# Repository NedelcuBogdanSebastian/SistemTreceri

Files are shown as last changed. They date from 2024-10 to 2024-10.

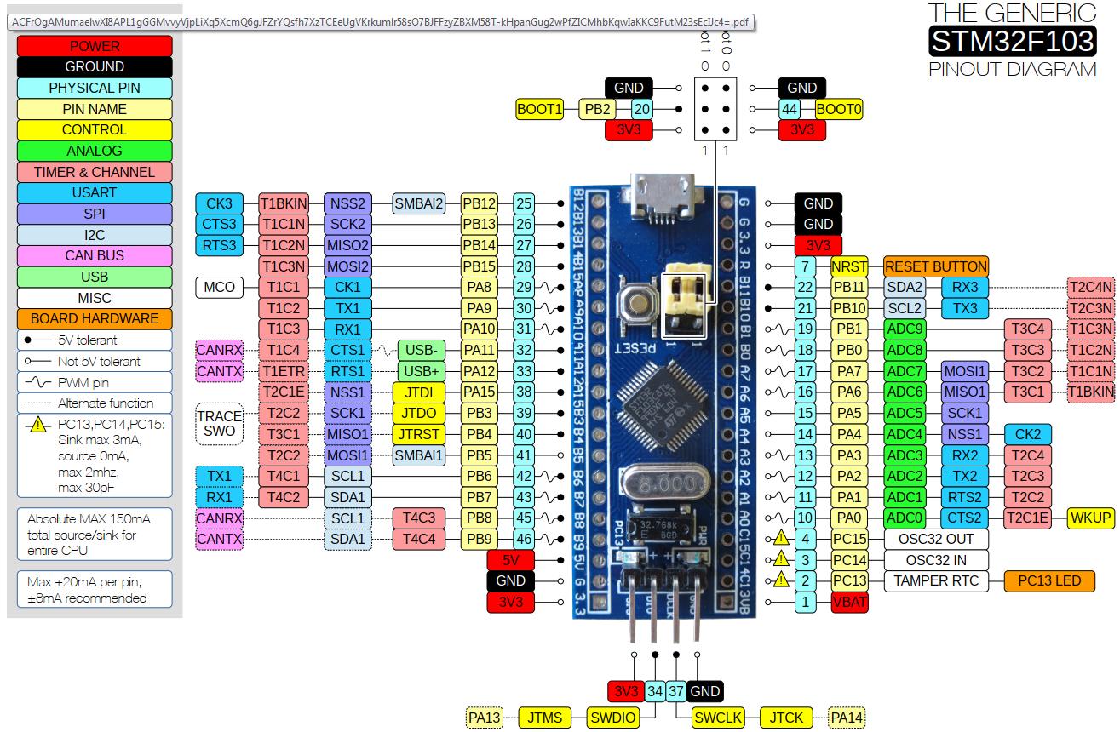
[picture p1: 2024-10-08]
Circuits/ZIntermediar2023/BLUEPILL-PINOUT.PNG

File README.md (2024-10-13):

display
# Copyright Notice
### Licence
Copyright (C) 2024 Nedelcu Bogdan Sebastian  
This code is free software: you can redistribute it and/or modify it under the following conditions:  
1. The use, distribution, and modification of this file are permitted for any purpose,  
   provided that the following conditions are met:  
2. Any redistribution or modification of this file must retain the original copyright notice,  
   this list of conditions, and the following attribution:  
      **"Original work by Nedelcu Bogdan Sebastian."**   
3. The original author provides no warranty regarding the functionality or fitness of this software  
   for any particular purpose. Use it at your own risk.  
By using this software, you agree to retain the name of the original author in any derivative works or distributions.  
This code is provided as-is, without any express or implied warranties.

# treceri
This is the main project used to acquire leakage currents signals, 
and compute **RMS voltage** and **phase** for each of the six channels.

The acquisition is starting after a **zero-cross detection**, and the length
of data is **2048 samples**.

The limits of the signals are between **2.678 mA** and **100 mA**.

More explanations of the algorithms are in the **main.c** file.

*(Note: The code runs on BluePill (STM32F103CBT6) and the IDE is the CooCox 1.7.8.
        The compiler used is the  gcc-arm-none-eabi-10.3-2021.10-win32.exe.
        Use external 23K256 SRAM memory to store all 6 signals at once!)*

# TestFFTPhaseComputation
This project also runs on the **STM32F103CBT6**.

Here we generate sine waves with phases from 0 to 359 degrees, and add noise to 
each signal and compute the phase angle from FFT.

The BluePill will show on the PC side as a **USB SERIAL** device, and we use this method
to print all values over **SERIAL**, the initial **signal phase** and the **computed phase** 
to further analyze them with Python if needed.

**Termite serial** can be used to receive data.

*(Note: The values are scaled by a factor of 10000 !)*

# treceriTestPhaseComputing

This project is made in **Visual Studio Code**. The compiler used is **tdm64-gcc-10.3.0-2**.

In this example we have the following:

    - we generate signals from 0 degrees to 359 degrees,
      of specific phase and noise, and write the values to files named `sine_wave_x.x.txt`,
      with 1.0 degree step
      
    - we generate the Flattop window and write coeffs to a file `flattop_window.txt`
    
    - we apply the window to the signal real side
    
    - we compute FFT
    
    - we compute the phase from bin 9 which is the nearest frequency from 50 Hz (51.4984130859375 Hz)

    - print computed data and repeat until the phase is >= 360.0 degrees
    
We also have some **Python** scripts we can use to see the signals from the files:

    - the `animate_plot_files.py` loads text files, one after another, 
      and plot the signal and the FFT
      
    - the `plot_sine_wave.py` plot only one file
    
    - the `gen_sig_hanning.py` generate a signal and apply hanning window. 
      Also compute phase.

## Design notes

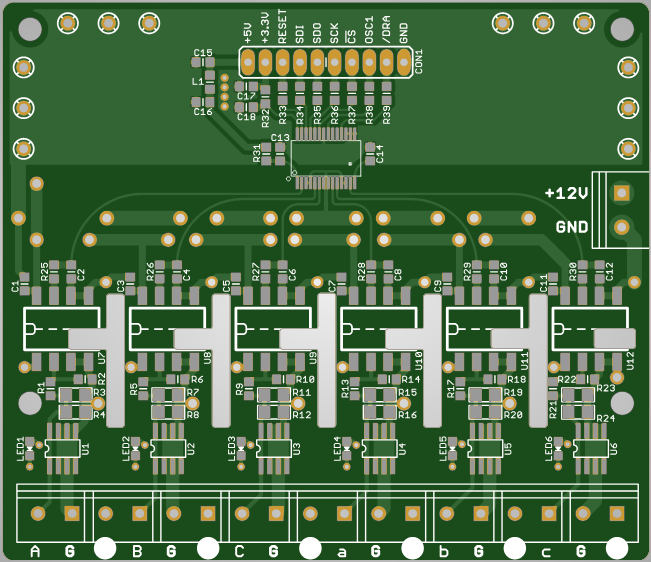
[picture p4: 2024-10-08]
Circuits/Zaq_ISO/Top.png

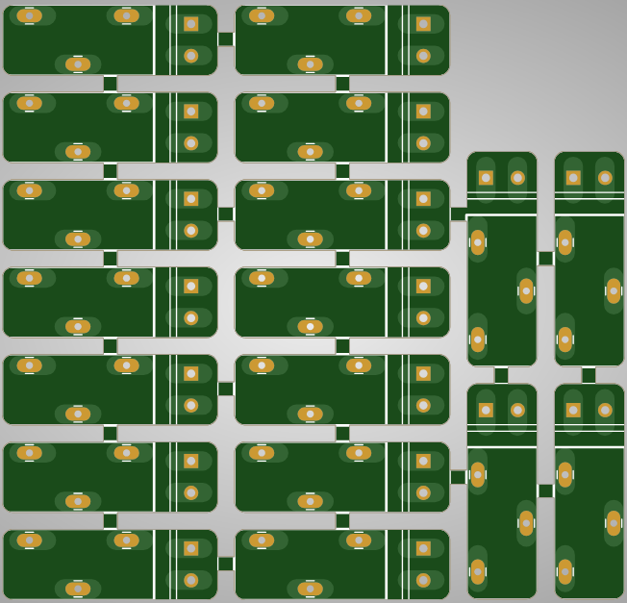
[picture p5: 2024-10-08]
Circuits/CT_Adapter/Top.png

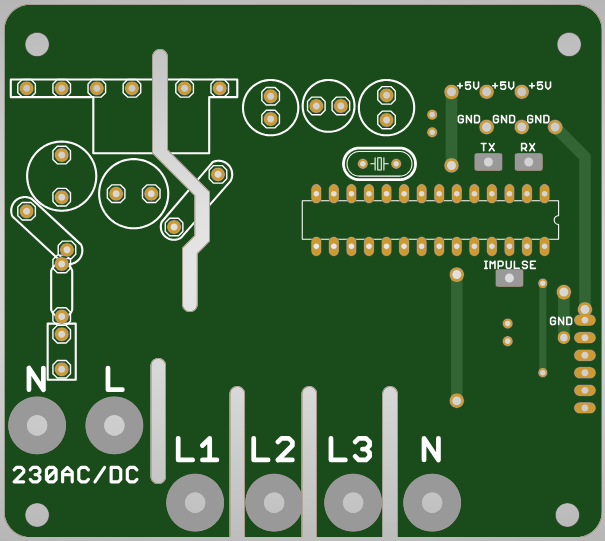
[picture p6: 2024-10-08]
Circuits/ZEROCROSS_ATmega328/Top.png

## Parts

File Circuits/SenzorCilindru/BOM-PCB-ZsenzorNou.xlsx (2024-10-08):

COMPONENTE
1x FAIR-RITE - 2944666661 - FERRITE CORE, CYLINDRICAL, 470 OHM
2x EPCOS - B88069X1380S102 - GAS DISCHARGE TUBE, 90V
4x SR PASSIVES MPEM-470NR15/250, CAPACITORS

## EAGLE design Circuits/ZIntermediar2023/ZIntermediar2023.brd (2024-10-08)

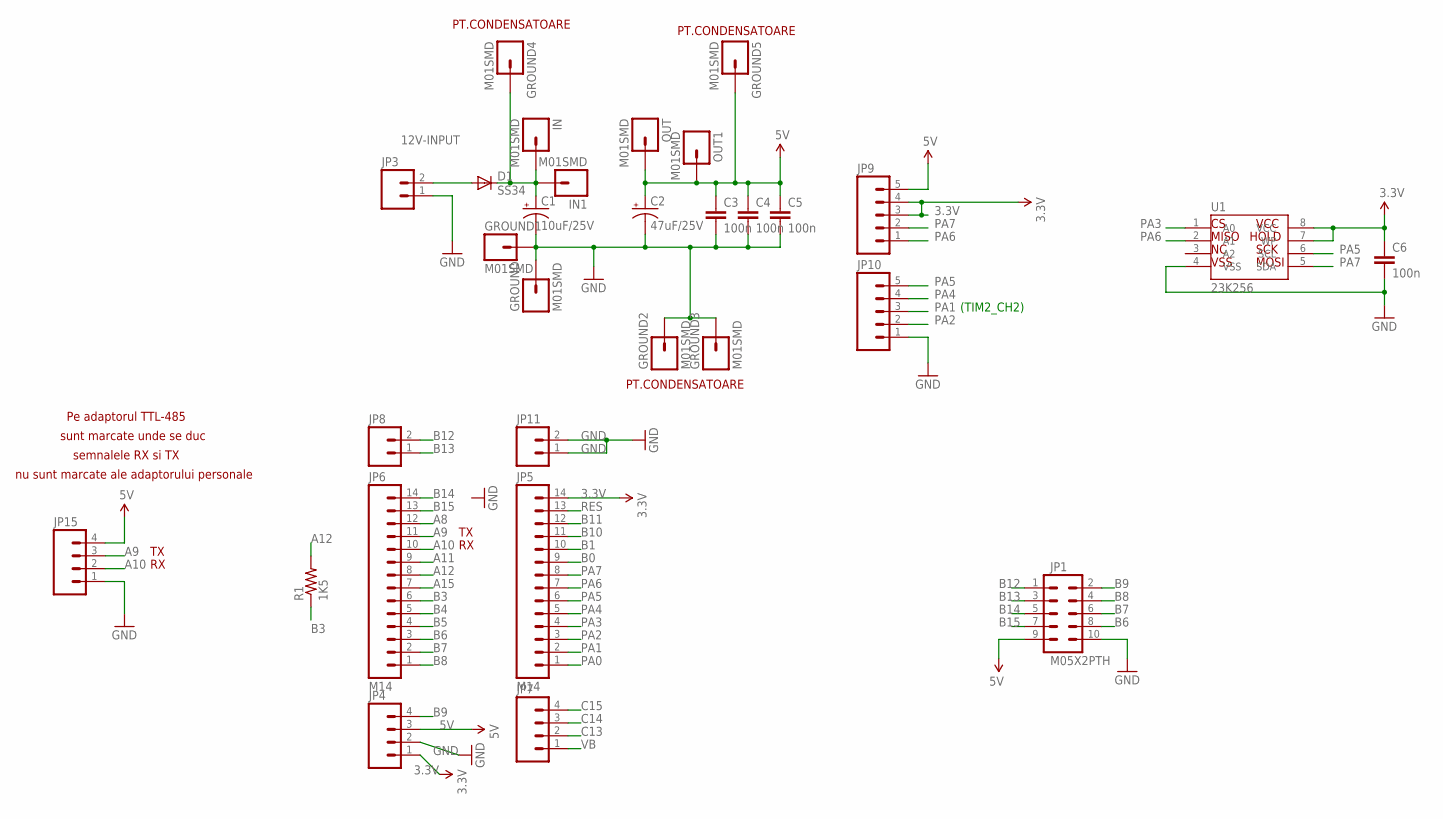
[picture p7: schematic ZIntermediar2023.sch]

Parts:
C1: 10uF/25V; PANASONIC_E
C2: 47uF/25V; PANASONIC_E
C3, C4, C5, C6: 100n; 1206
D1: SS34; SMC
GROUND, GROUND1, GROUND2, GROUND3, GROUND4, GROUND5: M01SMD; LUXEON-PAD
IN, IN1: M01SMD; LUXEON-PAD
JP1: M05X2PTH; AVR_ICSP
JP3: M025MM; SCREWTERMINAL-5MM-2
JP4, JP7: M04PTH; 1X04
JP5, JP6: M14; 1X14
JP8, JP11: M02PTH; 1X02
JP9, JP10: M05PTH_LONGPADS; 1X05_LONGPADS
JP15: M04LONGPADS; 1X04_LONGPADS
OUT, OUT1: M01SMD; LUXEON-PAD
R1: 1K5; 1206
U1: 23K256; SO08

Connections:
3.3V: C6.1, JP4.1, JP5.14, JP9.3, JP9.4, U1.7 (WP), U1.8 (VCC)
5V: C2.+, C3.1, C4.1, C5.1, GROUND5.P$1, JP1.9, JP4.3, JP9.5, JP15.4, OUT.P$1, OUT1.P$1
12V-INPUT: C1.+, D1.C, GROUND4.P$1, IN.P$1, IN1.P$1
A8: JP6.12
A9: JP6.11, JP15.3
A10: JP6.10, JP15.2
A11: JP6.9
A12: JP6.8, R1.2
A15: JP6.7
B0: JP5.9
B1: JP5.10
B3: JP6.6, R1.1
B4: JP6.5
B5: JP6.4
B6: JP1.8, JP6.3
B7: JP1.6, JP6.2
B8: JP1.4, JP6.1
B9: JP1.2, JP4.4
B10: JP5.11
B11: JP5.12
B12: JP1.1, JP8.2
B13: JP1.3, JP8.1
B14: JP1.5, JP6.14
B15: JP1.7, JP6.13
C13: JP7.2
C14: JP7.3
C15: JP7.4
GND: C1.-, C2.-, C3.2, C4.2, C5.2, C6.2, GROUND.P$1, GROUND1.P$1, GROUND2.P$1, GROUND3.P$1, JP1.10, JP3.1, JP4.2, JP10.1, JP11.1, JP11.2, JP15.1, U1.4 (VSS)
unnamed: D1.A, JP3.2
PA0: JP5.1
PA1: JP5.2, JP10.3
PA2: JP5.3, JP10.2
PA3: JP5.4, U1.1 (A0)
PA4: JP5.5, JP10.4
PA5: JP5.6, JP10.5, U1.6 (SCL)
PA6: JP5.7, JP9.1, U1.2 (A1)
PA7: JP5.8, JP9.2, U1.5 (SDA)
RES: JP5.13
VB: JP7.1

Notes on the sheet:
(TIM2_CH2)
MISO
VSS
VCC
HOLD
SCK
MOSI
PT.CONDENSATOARE
Pe adaptorul TTL-485
sunt marcate unde se duc
semnalele RX si TX
nu sunt marcate ale adaptorului personale

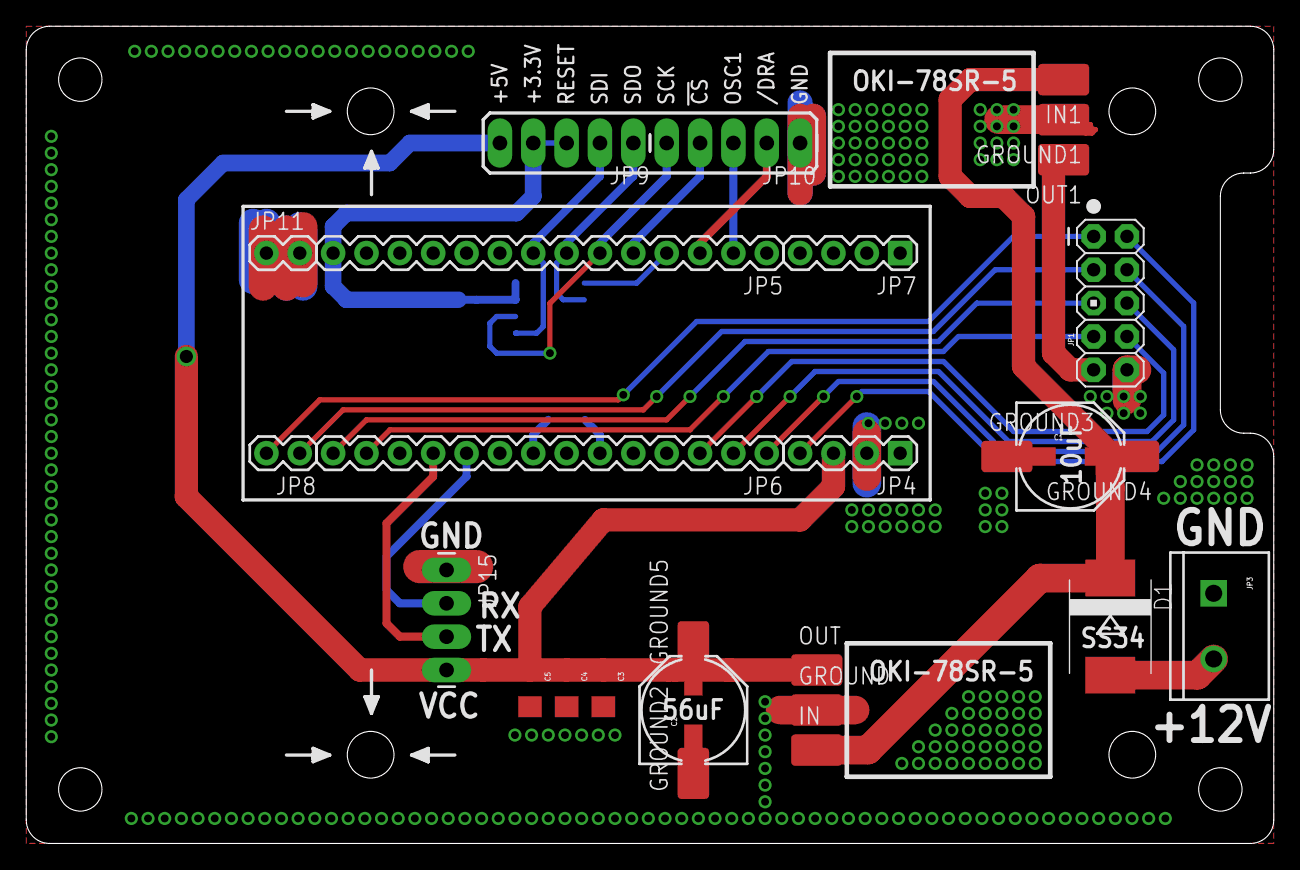
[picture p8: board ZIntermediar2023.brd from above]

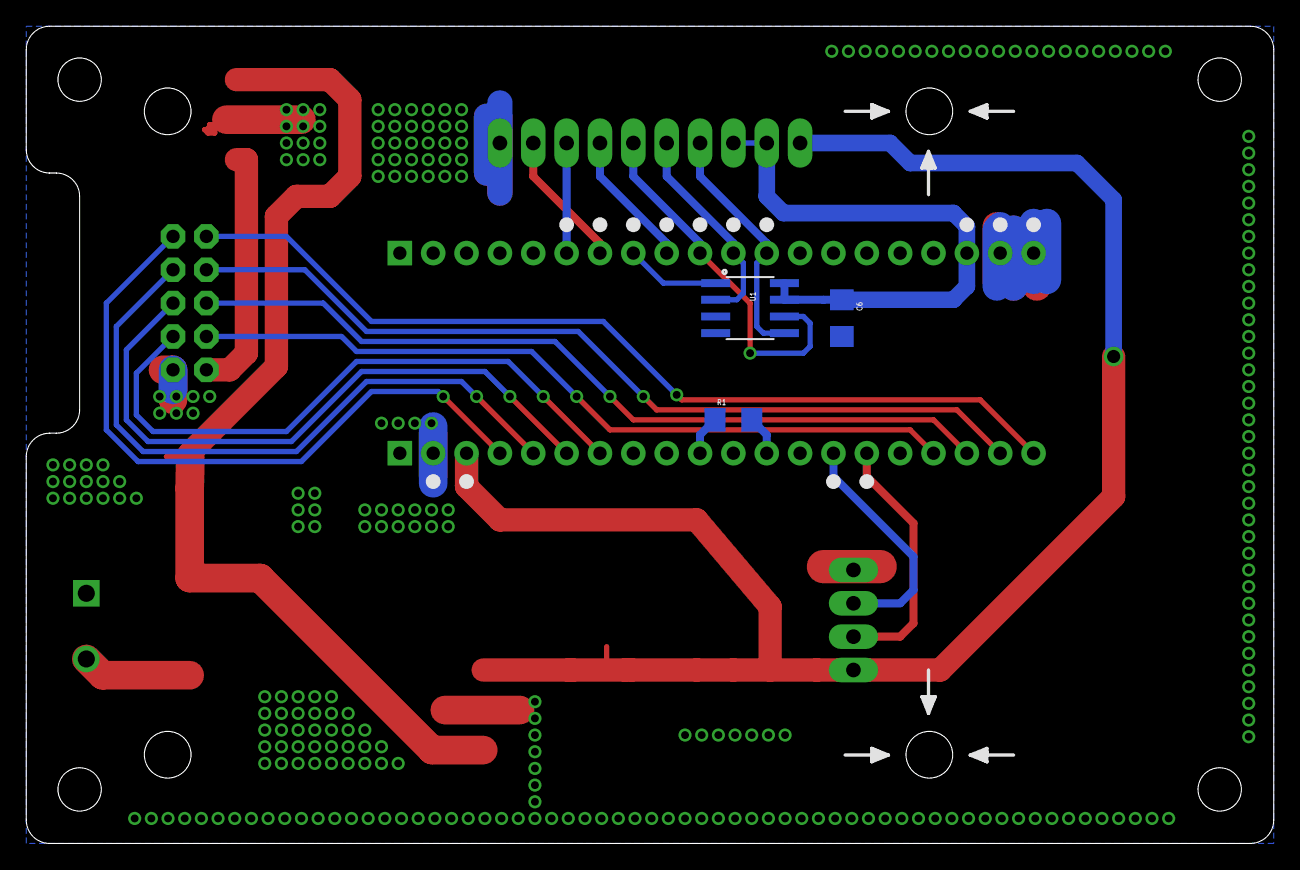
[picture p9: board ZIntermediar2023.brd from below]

Board: 2 copper layers, 95.0 x 62.2 mm, 34 parts (3 on the bottom side), 24 nets.

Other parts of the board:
STANDOFF1, STANDOFF6, STANDOFF10, STANDOFF12: STAND-OFF

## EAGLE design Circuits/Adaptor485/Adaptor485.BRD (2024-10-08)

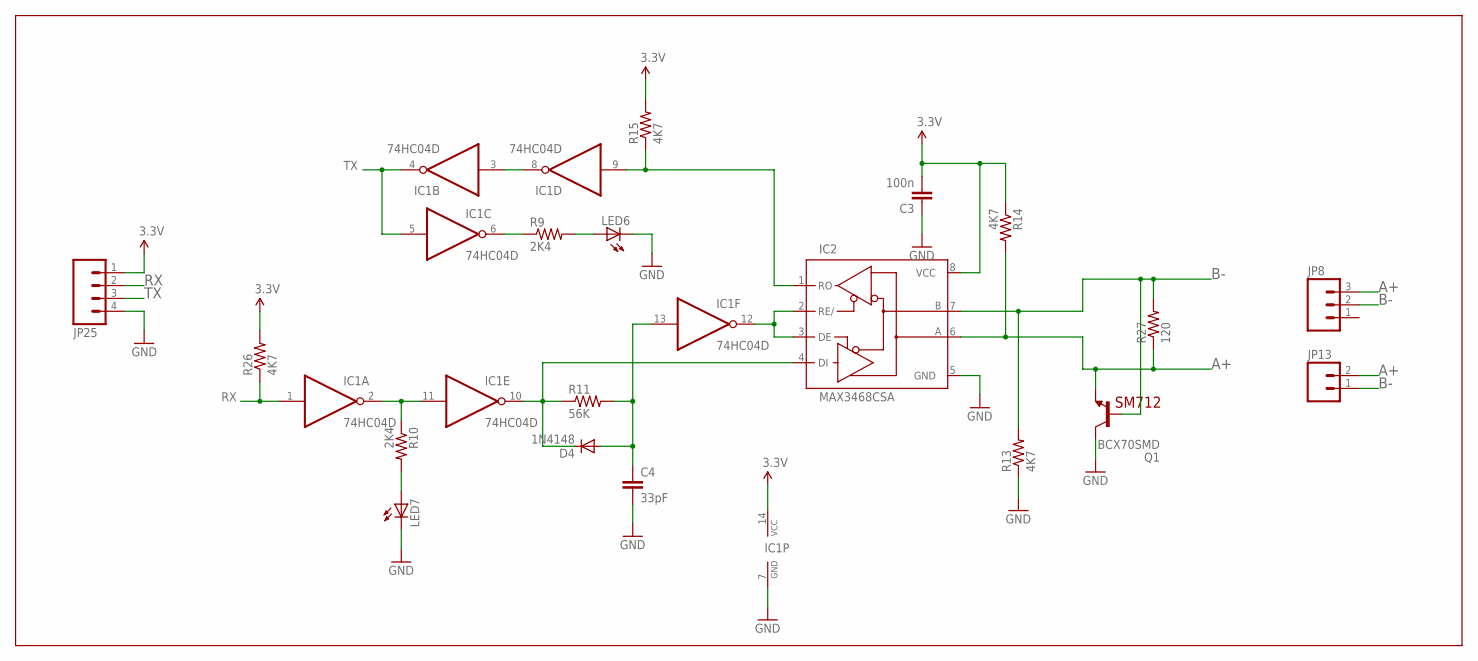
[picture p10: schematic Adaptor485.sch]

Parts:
C3: 100n; 0805
C4: 33pF; 0805
D4: 1N4148; MINIMELF
IC1: 74HC04D; SO14
IC2: MAX3468CSA; SO08
JP8: M03-SCREW-5MM; SCREWTERMINAL-5MM-3
JP13: M025MM; SCREWTERMINAL-5MM-2
JP25: M04PTH; 1X04
LED6, LED7: LEDCHIP-LED0805; CHIP-LED0805
Q1: BCX70SMD; SOT23
R9, R10: 2K4; 0805
R11: 56K; 0805
R13, R14, R15, R26: 4K7; 0805
R27: 120; 0805

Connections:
3.3V: C3.2, IC1.14 (VCC), IC2.8 (VCC), JP25.1, R14.1, R15.2, R26.2
A+: IC2.6 (A), JP8.3, JP13.2, Q1.2 (E), R14.2, R27.1
B-: IC2.7 (B), JP8.2, JP13.1, Q1.1 (B), R13.2, R27.2
GND: C3.1, C4.2, IC1.7 (GND), IC2.5 (GND), JP25.4, LED6.C, LED7.C, Q1.3 (C), R13.1
unnamed: LED7.A, R10.2
unnamed: LED6.A, R9.2
unnamed: IC1.2 (O), IC1.11 (I), R10.1
unnamed: IC1.9 (I), IC2.1 (RO), R15.1
unnamed: IC1.3 (I), IC1.8 (O)
unnamed: C4.1, D4.A, IC1.13 (I), R11.2
unnamed: IC1.6 (O), R9.1
unnamed: D4.C, IC1.10 (O), IC2.4 (DI), R11.1
unnamed: IC1.12 (O), IC2.2 (RE/), IC2.3 (DE)
RX: IC1.1 (I), JP25.2, R26.1
TX: IC1.4 (O), IC1.5 (I), JP25.3

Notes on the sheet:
SM712

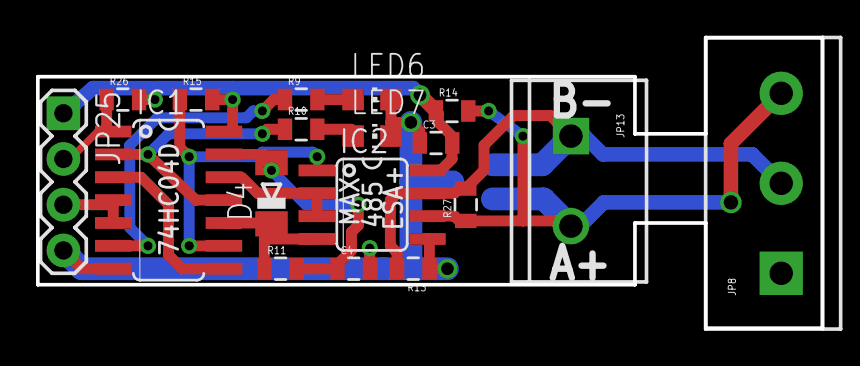
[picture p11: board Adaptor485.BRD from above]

Board: 2 copper layers, 43.6 x 16.1 mm, 19 parts (1 on the bottom side), 15 nets.

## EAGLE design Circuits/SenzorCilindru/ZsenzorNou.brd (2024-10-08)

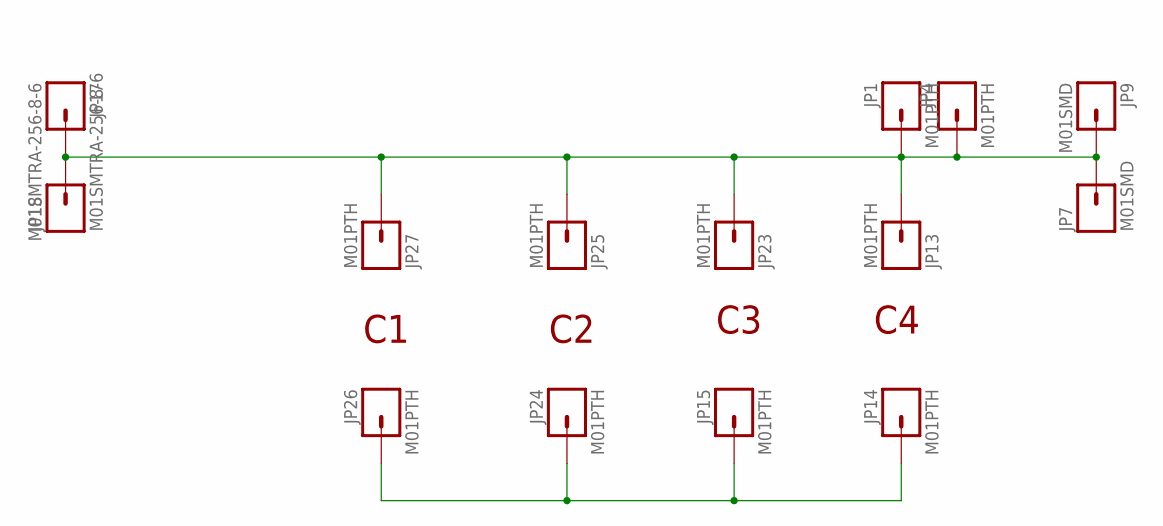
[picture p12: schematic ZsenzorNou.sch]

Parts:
JP1, JP4, JP13, JP14, JP15, JP23, JP24, JP25, JP26, JP27: M01PTH; 1X01
JP7, JP9: M01SMD; LUXEON-PAD
JP17, JP18: M01SMTRA-256-8-6; SMTRA-256-8-6

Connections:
GND: JP14.1, JP15.1, JP24.1, JP26.1
unnamed: JP1.1, JP4.1, JP7.P$1, JP9.P$1, JP13.1, JP17.P$1, JP18.P$1, JP23.1, JP25.1, JP27.1

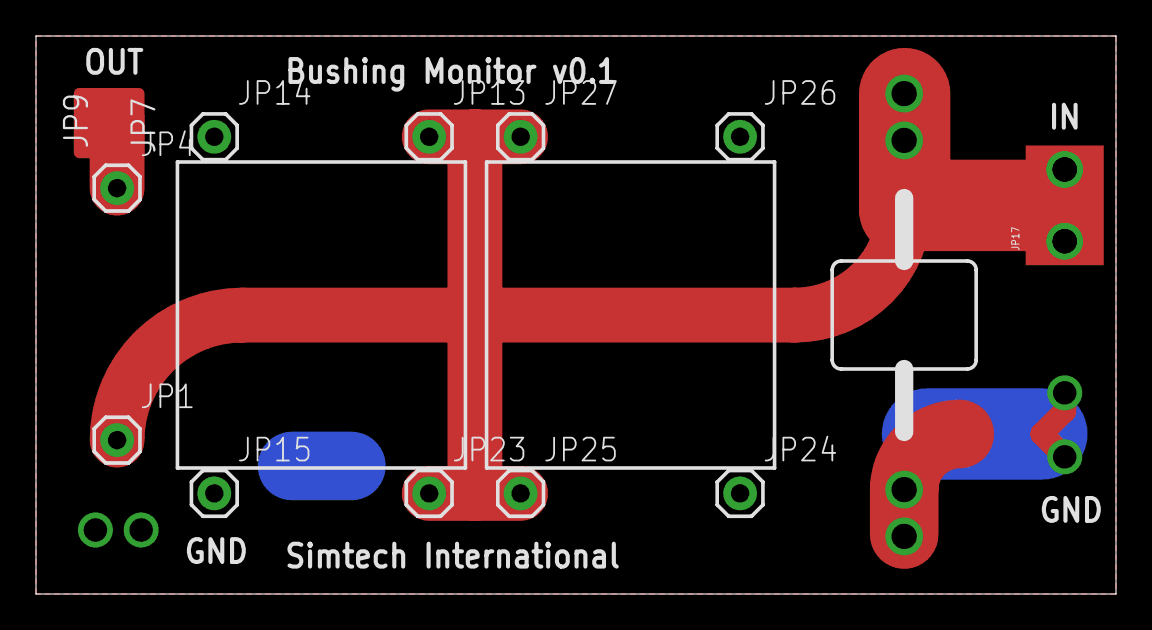
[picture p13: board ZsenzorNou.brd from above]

Board: 2 copper layers, 60.0 x 31.0 mm, 14 parts (1 on the bottom side), 2 nets.

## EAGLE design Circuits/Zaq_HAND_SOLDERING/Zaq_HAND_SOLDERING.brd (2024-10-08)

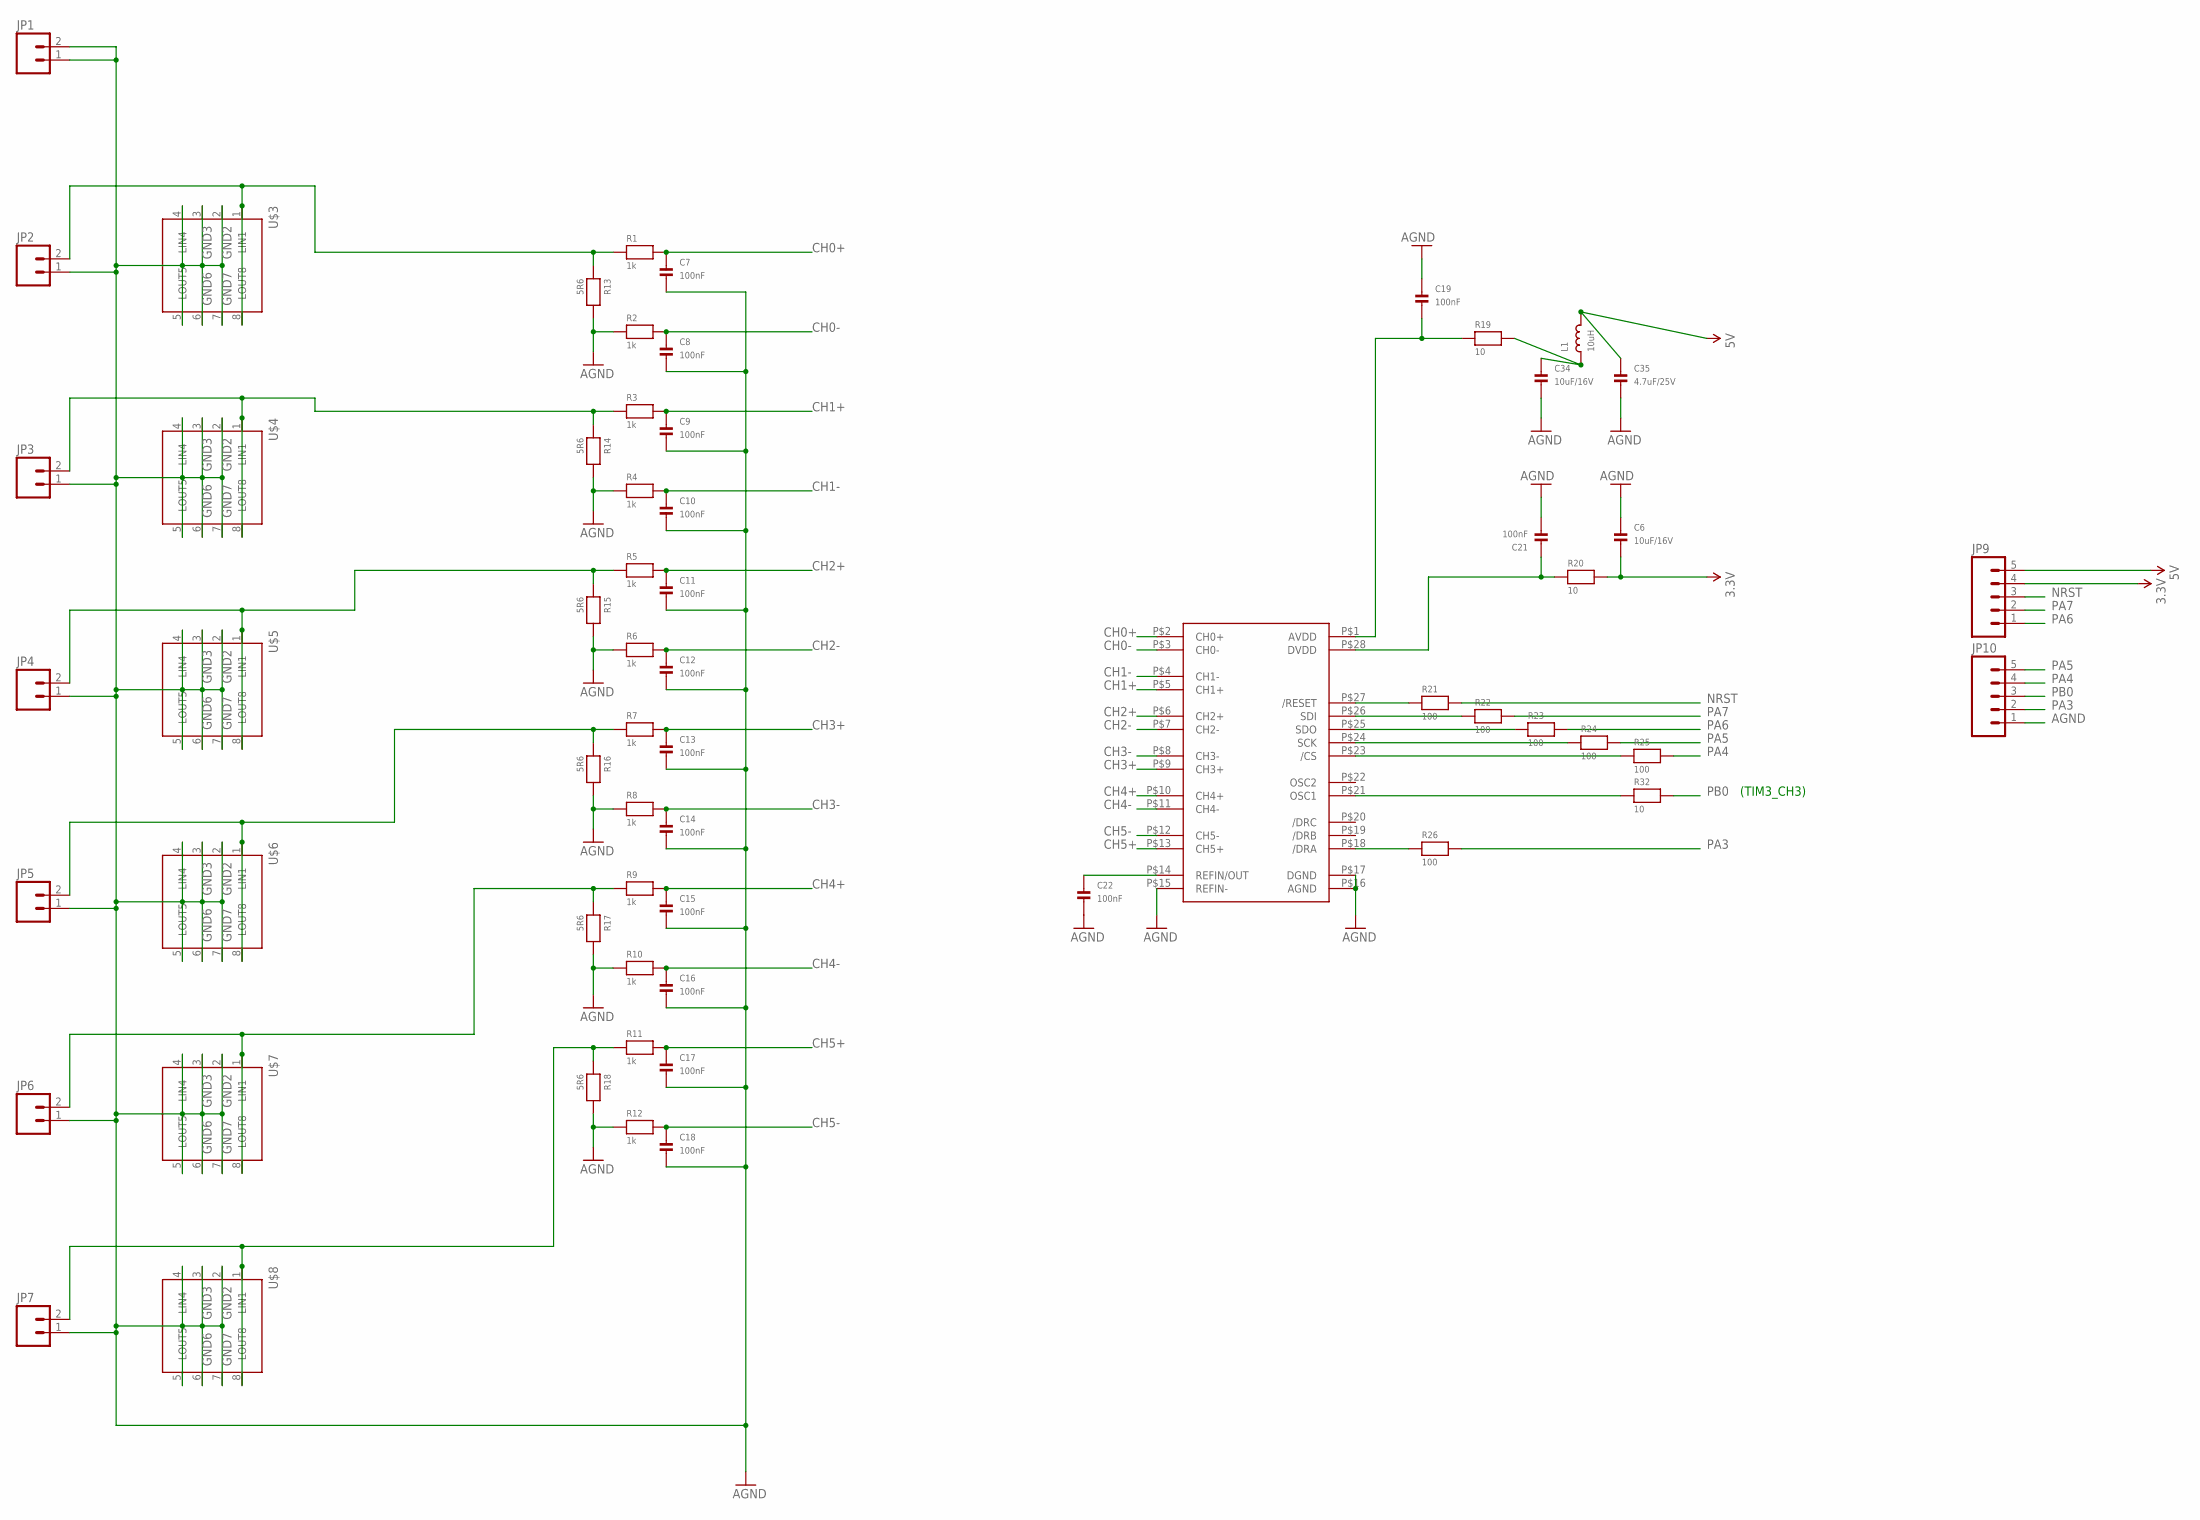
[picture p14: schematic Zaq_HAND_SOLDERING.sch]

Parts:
.: MCP3903; SSOP-28
C6, C34: 10uF/16V; _0805MP
C7, C8, C9, C10, C11, C12, C13, C14, C15, C16, C17, C18, C19, C21, C22: 100nF; _0805MP
C35: 4.7uF/25V; _0805MP
JP1, JP2, JP3, JP4, JP5, JP6, JP7: M025MM; SCREWTERMINAL-5MM-2
JP9, JP10: M05PTH_LONGPADS; 1X05_LONGPADS
L1: 10uH; _0805MP
R1, R2, R3, R4, R5, R6, R7, R8, R9, R10, R11, R12: 1k; _0805MP
R13, R14, R15, R16, R17, R18: 5R6; 1206
R19, R20, R32: 10; _0805MP
R21, R22, R23, R24, R25, R26: 100; _0805MP
U$3, U$4, U$5, U$6, U$7, U$8: LC03_3V3; SO8

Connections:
3.3V: C6.2, JP9.4, R20.2
5V: C35.1, JP9.5, L1.2
AGND: ..P$15 (REFIN-), ..P$16 (AGND), ..P$17 (DGND), C6.1, C7.2, C8.2, C9.2, C10.2, C11.2, C12.2, C13.2, C14.2, C15.2, C16.2, C17.2, C18.2, C19.1, C21.2, C22.2, C34.2, C35.2, JP1.1, JP1.2, JP2.1, JP3.1, JP4.1, JP5.1, JP6.1, JP7.1, JP10.1, R2.1, R4.1, R6.1, R8.1, R10.1, R12.1, R13.2, R14.2, R15.2, R16.2, R17.2, R18.2, U$3.2 (GND_2), U$3.3 (GND_3), U$3.4 (LIN4), U$3.5 (LOUT5), U$3.6 (GND_6), U$3.7 (GND_7), U$4.2 (GND_2), U$4.3 (GND_3), U$4.4 (LIN4), U$4.5 (LOUT5), U$4.6 (GND_6), U$4.7 (GND_7), U$5.2 (GND_2), U$5.3 (GND_3), U$5.4 (LIN4), U$5.5 (LOUT5), U$5.6 (GND_6), U$5.7 (GND_7), U$6.2 (GND_2), U$6.3 (GND_3), U$6.4 (LIN4), U$6.5 (LOUT5), U$6.6 (GND_6), U$6.7 (GND_7), U$7.2 (GND_2), U$7.3 (GND_3), U$7.4 (LIN4), U$7.5 (LOUT5), U$7.6 (GND_6), U$7.7 (GND_7), U$8.2 (GND_2), U$8.3 (GND_3), U$8.4 (LIN4), U$8.5 (LOUT5), U$8.6 (GND_6), U$8.7 (GND_7)
CH0+: ..P$2 (CH0+), C7.1, R1.2
CH0-: ..P$3 (CH0-), C8.1, R2.2
CH1+: ..P$5 (CH1+), C9.1, R3.2
CH1-: ..P$4 (CH1-), C10.1, R4.2
CH2+: ..P$6 (CH2+), C11.1, R5.2
CH2-: ..P$7 (CH2-), C12.1, R6.2
CH3+: ..P$9 (CH3+), C13.1, R7.2
CH3-: ..P$8 (CH3-), C14.1, R8.2
CH4+: ..P$10 (CH4+), C15.1, R9.2
CH4-: ..P$11 (CH4-), C16.1, R10.2
CH5+: ..P$13 (CH5+), C17.1, R11.2
CH5-: ..P$12 (CH5-), C18.1, R12.2
unnamed: ..P$21 (OSC1), R32.1
unnamed: ..P$1 (AVDD), C19.2, R19.1
unnamed: ..P$14 (REFIN/OUT), C22.1
unnamed: ..P$28 (DVDD), C21.1, R20.1
unnamed: ..P$27 (/RESET), R21.1
unnamed: ..P$26 (SDI), R22.1
unnamed: ..P$25 (SDO), R23.1
unnamed: ..P$24 (SCK), R24.1
unnamed: ..P$23 (/CS), R25.1
unnamed: ..P$18 (/DRA), R26.1
unnamed: C34.1, L1.1, R19.2
unnamed: JP7.2, R11.1, R18.1, U$8.1 (LIN1), U$8.8 (LOUT8)
unnamed: JP6.2, R9.1, R17.1, U$7.1 (LIN1), U$7.8 (LOUT8)
unnamed: JP5.2, R7.1, R16.1, U$6.1 (LIN1), U$6.8 (LOUT8)
unnamed: JP4.2, R5.1, R15.1, U$5.1 (LIN1), U$5.8 (LOUT8)
unnamed: JP3.2, R3.1, R14.1, U$4.1 (LIN1), U$4.8 (LOUT8)
unnamed: JP2.2, R1.1, R13.1, U$3.1 (LIN1), U$3.8 (LOUT8)
NRST: JP9.3, R21.2
PA3: JP10.2, R26.2
PA4: JP10.4, R25.2
PA5: JP10.5, R24.2
PA6: JP9.1, R23.2
PA7: JP9.2, R22.2
PB0: JP10.3, R32.2

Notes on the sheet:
(TIM3_CH3)

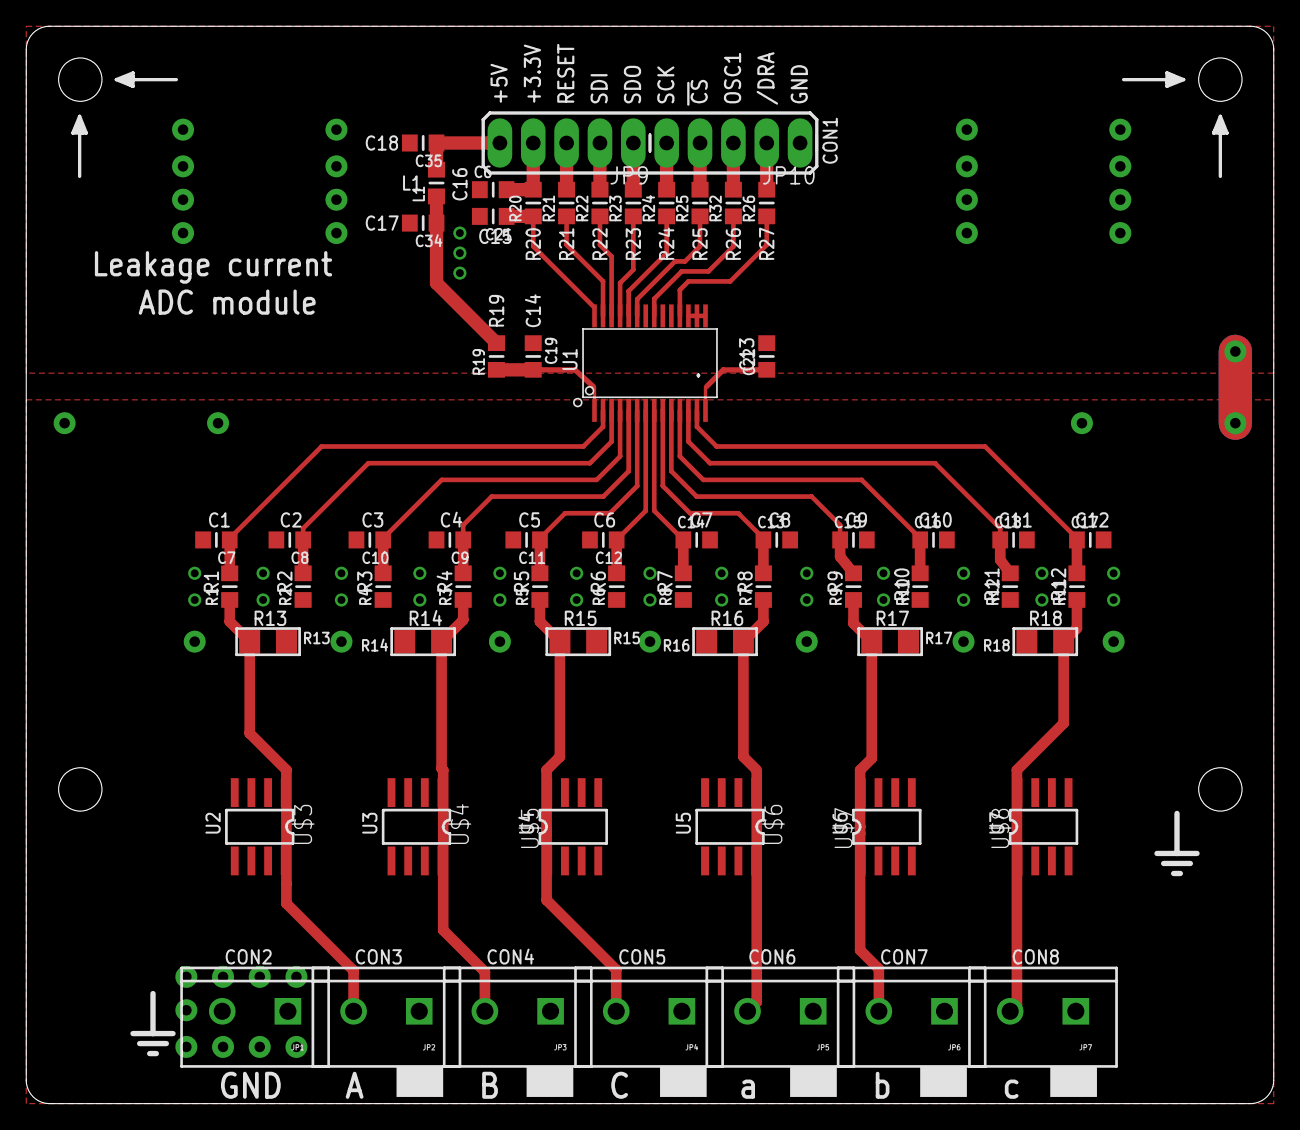
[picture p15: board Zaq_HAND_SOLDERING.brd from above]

Board: 2 copper layers, 95.0 x 82.0 mm, 66 parts (0 on the bottom side), 39 nets.

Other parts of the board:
STANDOFF1, STANDOFF6, STANDOFF10, STANDOFF12: STAND-OFF

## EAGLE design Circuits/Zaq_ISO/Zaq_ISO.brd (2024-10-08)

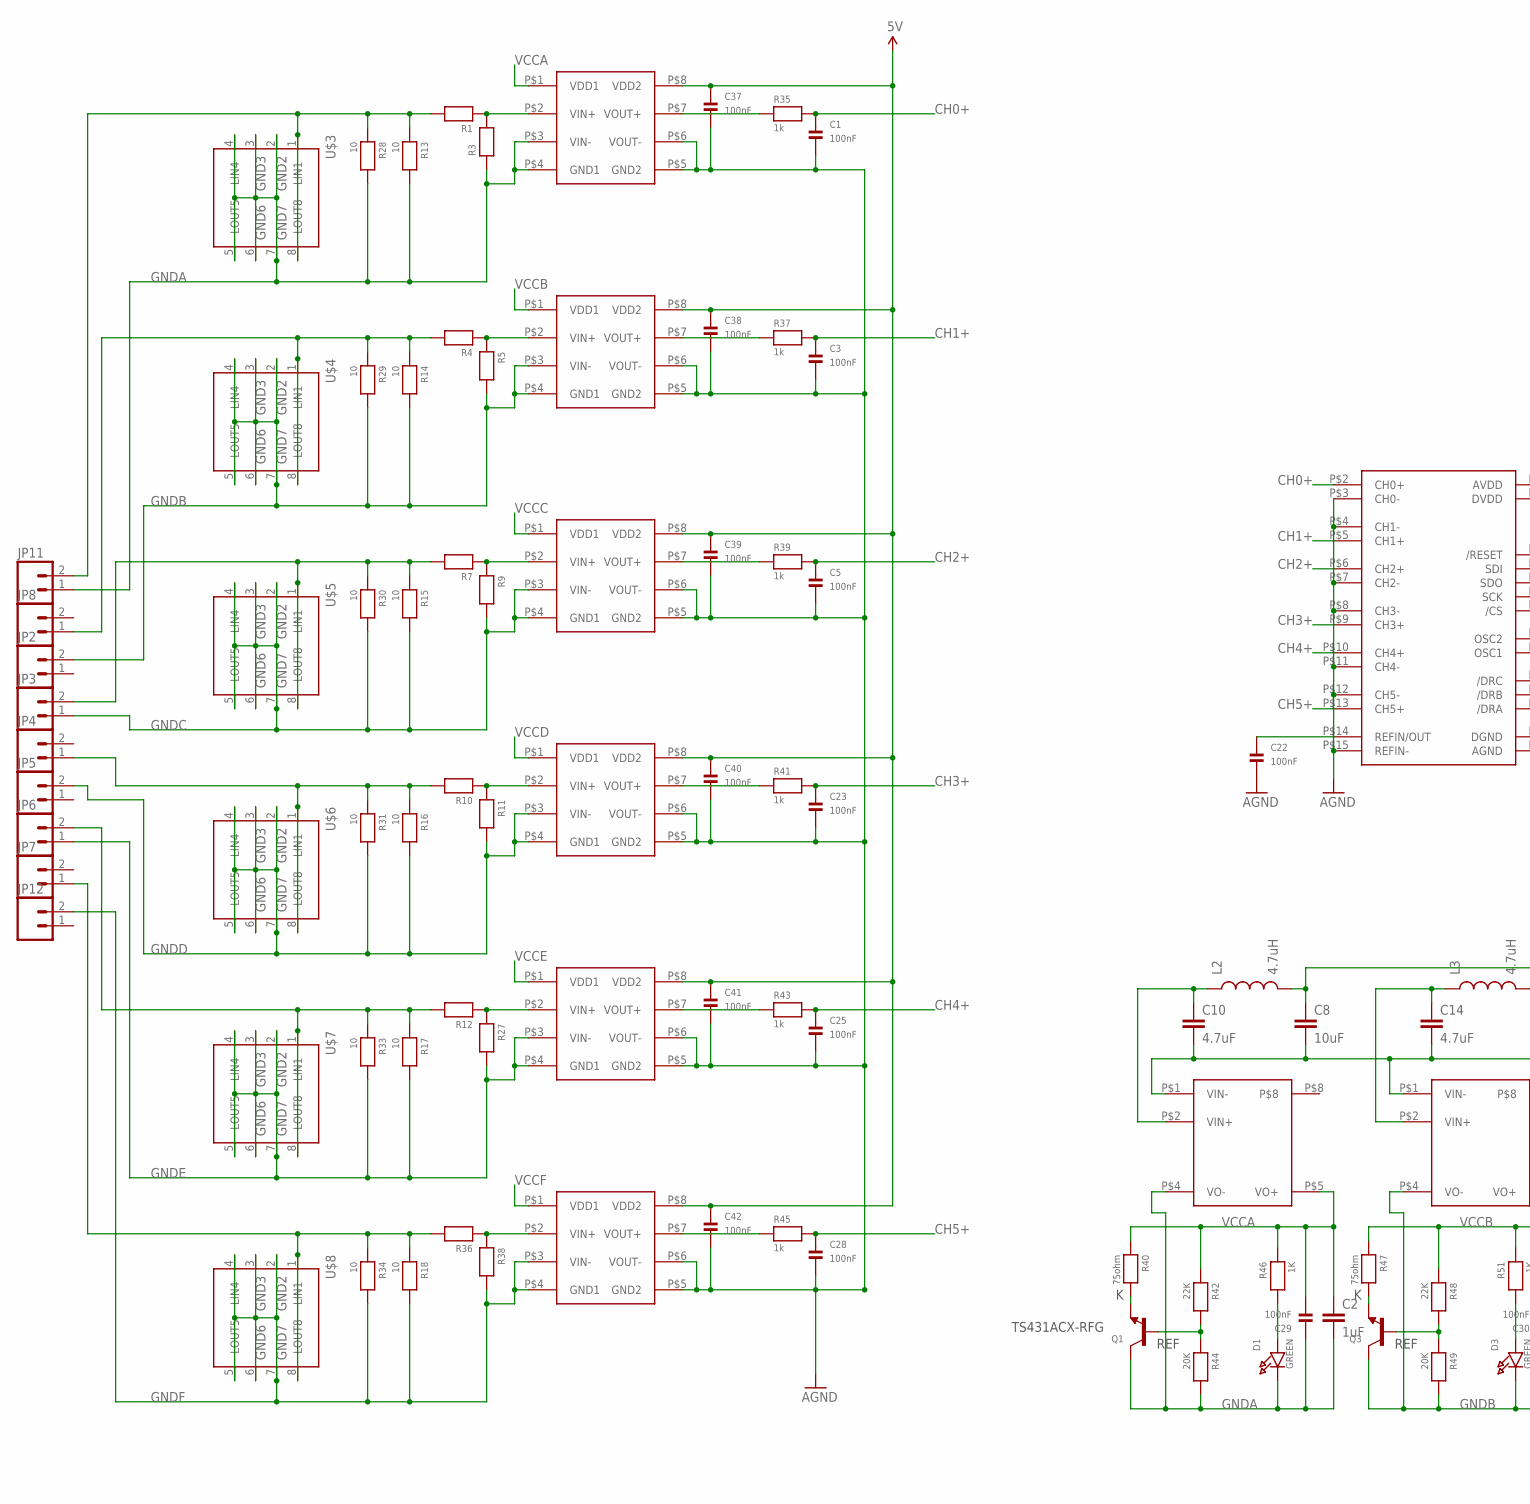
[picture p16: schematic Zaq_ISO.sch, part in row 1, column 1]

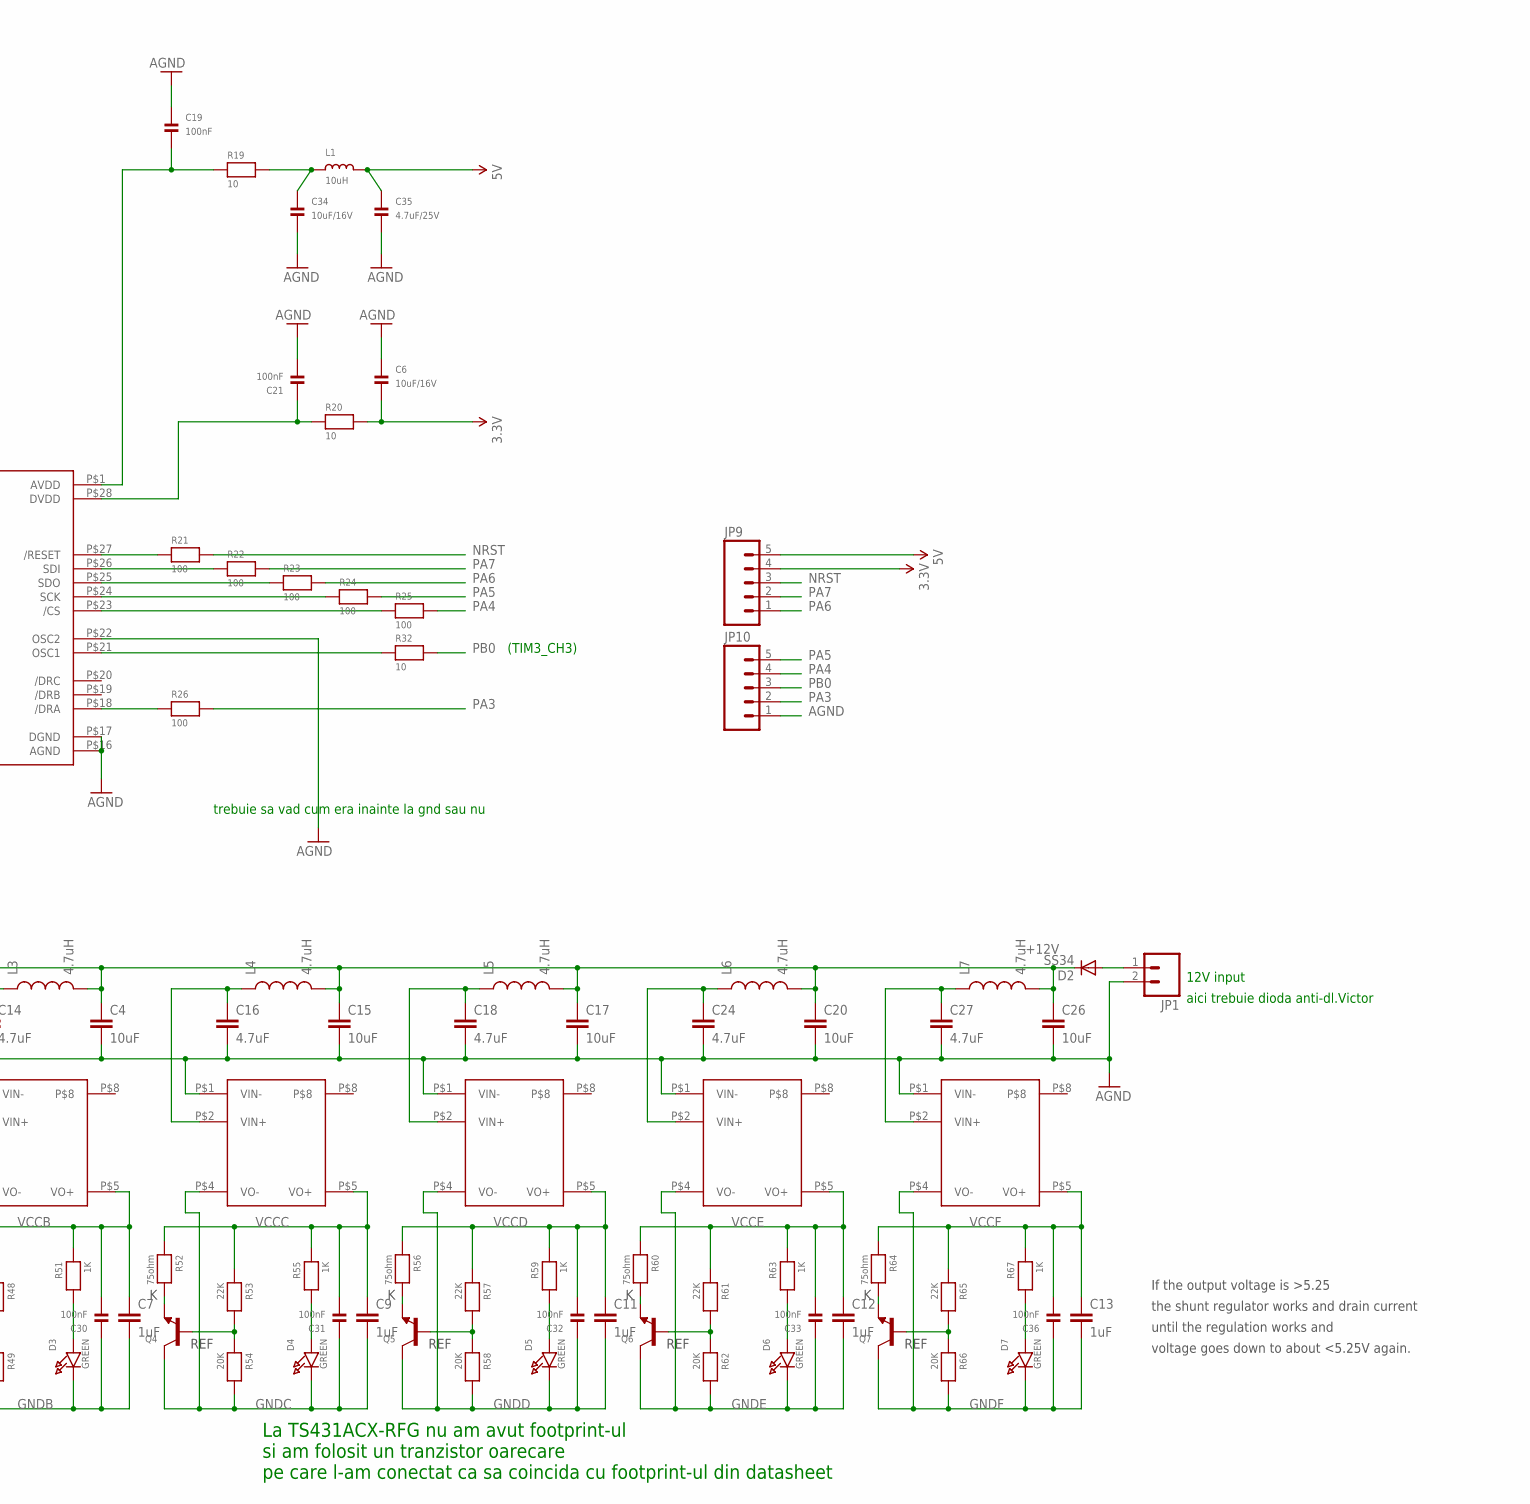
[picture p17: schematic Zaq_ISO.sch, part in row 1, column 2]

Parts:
.: MCP3903; SSOP-28
C1, C3, C5, C19, C21, C22, C23, C25, C28, C29, C30, C31, C32, C33, C36, C37, C38, C39, C40, C41, C42: 100nF; _0805MP
C2, C7, C9, C11, C12, C13: 1uF; 1206
C4, C8, C15, C17, C20, C26: 10uF; 1206
C6, C34: 10uF/16V; _0805MP
C10, C14, C16, C18, C24, C27: 4.7uF; 1206
C35: 4.7uF/25V; _0805MP
D1, D3, D4, D5, D6, D7: GREEN; CHIPLED_0805_NOOUTLINE
D2: SS34; SMC
JP1, JP2, JP3, JP4, JP5, JP6, JP7, JP8, JP11, JP12: M025MM; SCREWTERMINAL-5MM-2
JP9, JP10: M05PTH_LONGPADS; 1X05_LONGPADS
L1: 10uH; _0805MP
L2, L3, L4, L5, L6, L7: 4.7uH; 1210
Q1, Q3, Q4, Q5, Q6, Q7: TRANSISTOR_NPNWAVE; SOT23-W
R1, R3, R4, R5, R7, R9, R10, R11, R12, R27, R36, R38: RESISTOR_0805MP; _0805MP
R13, R14, R15, R16, R17, R18, R28, R29, R30, R31, R33, R34: 10; 1206
R19, R20, R32: 10; _0805MP
R21, R22, R23, R24, R25, R26: 100; _0805MP
R35, R37, R39, R41, R43, R45: 1k; _0805MP
R40, R47, R52, R56, R60, R64: 75ohm; _0805MP
R42, R48, R53, R57, R61, R65: 22K; _0805MP
R44, R49, R54, R58, R62, R66: 20K; _0805MP
R46, R51, R55, R59, R63, R67: 1K; _0805MP
U$2, U$9, U$12, U$16, U$18, U$19: AMC1200SDUB; SOP
U$3, U$4, U$5, U$6, U$7, U$8: LC03_3V3; SO8
U$17, U$20, U$22, U$23, U$24, U$25: AM1LS-NJZ; AM1LS-JZ

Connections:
3.3V: C6.2, JP9.4, R20.2
5V: C35.1, C37.1, C38.1, C39.1, C40.1, C41.1, C42.1, JP9.5, L1.2, U$2.P$8 (VDD2), U$9.P$8 (VDD2), U$12.P$8 (VDD2), U$16.P$8 (VDD2), U$18.P$8 (VDD2), U$19.P$8 (VDD2)
+12V: C4.1, C8.1, C15.1, C17.1, C20.1, C26.1, D2.C, L2.2, L3.2, L4.2, L5.2, L6.2, L7.2
AGND: ..P$3 (CH0-), ..P$4 (CH1-), ..P$7 (CH2-), ..P$8 (CH3-), ..P$11 (CH4-), ..P$12 (CH5-), ..P$15 (REFIN-), ..P$16 (AGND), ..P$17 (DGND), ..P$22 (OSC2), C1.2, C3.2, C4.2, C5.2, C6.1, C8.2, C10.2, C14.2, C15.2, C16.2, C17.2, C18.2, C19.1, C20.2, C21.2, C22.2, C23.2, C24.2, C25.2, C26.2, C27.2, C28.2, C34.2, C35.2, C37.2, C38.2, C39.2, C40.2, C41.2, C42.2, JP1.2, JP10.1, U$2.P$5 (GND2), U$2.P$6 (VOUT-), U$9.P$5 (GND2), U$9.P$6 (VOUT-), U$12.P$5 (GND2), U$12.P$6 (VOUT-), U$16.P$5 (GND2), U$16.P$6 (VOUT-), U$17.P$1 (VIN-), U$18.P$5 (GND2), U$18.P$6 (VOUT-), U$19.P$5 (GND2), U$19.P$6 (VOUT-), U$20.P$1 (VIN-), U$22.P$1 (VIN-), U$23.P$1 (VIN-), U$24.P$1 (VIN-), U$25.P$1 (VIN-)
CH0+: ..P$2 (CH0+), C1.1, R35.2
CH1+: ..P$5 (CH1+), C3.1, R37.2
CH2+: ..P$6 (CH2+), C5.1, R39.2
CH3+: ..P$9 (CH3+), C23.1, R41.2
CH4+: ..P$10 (CH4+), C25.1, R43.2
CH5+: ..P$13 (CH5+), C28.1, R45.2
GNDA: C2.2, C29.1, D1.C, JP11.1, Q1.3 (C), R3.1, R13.2, R28.2, R44.2, U$2.P$3 (VIN-), U$2.P$4 (GND1), U$3.2 (GND_2), U$3.3 (GND_3), U$3.4 (LIN4), U$3.5 (LOUT5), U$3.6 (GND_6), U$3.7 (GND_7), U$17.P$4 (VO-)
GNDB: C7.2, C30.1, D3.C, JP2.2, Q3.3 (C), R5.2, R14.2, R29.2, R49.2, U$4.2 (GND_2), U$4.3 (GND_3), U$4.4 (LIN4), U$4.5 (LOUT5), U$4.6 (GND_6), U$4.7 (GND_7), U$9.P$3 (VIN-), U$9.P$4 (GND1), U$20.P$4 (VO-)
GNDC: C9.2, C31.1, D4.C, JP3.1, Q4.3 (C), R9.2, R15.2, R30.2, R54.2, U$5.2 (GND_2), U$5.3 (GND_3), U$5.4 (LIN4), U$5.5 (LOUT5), U$5.6 (GND_6), U$5.7 (GND_7), U$12.P$3 (VIN-), U$12.P$4 (GND1), U$22.P$4 (VO-)
GNDD: C11.2, C32.1, D5.C, JP5.2, Q5.3 (C), R11.2, R16.2, R31.2, R58.2, U$6.2 (GND_2), U$6.3 (GND_3), U$6.4 (LIN4), U$6.5 (LOUT5), U$6.6 (GND_6), U$6.7 (GND_7), U$16.P$3 (VIN-), U$16.P$4 (GND1), U$23.P$4 (VO-)
GNDE: C12.2, C33.1, D6.C, JP6.1, Q6.3 (C), R17.2, R27.2, R33.2, R62.2, U$7.2 (GND_2), U$7.3 (GND_3), U$7.4 (LIN4), U$7.5 (LOUT5), U$7.6 (GND_6), U$7.7 (GND_7), U$18.P$3 (VIN-), U$18.P$4 (GND1), U$24.P$4 (VO-)
GNDF: C13.2, C36.1, D7.C, JP12.2, Q7.3 (C), R18.2, R34.2, R38.2, R66.2, U$8.2 (GND_2), U$8.3 (GND_3), U$8.4 (LIN4), U$8.5 (LOUT5), U$8.6 (GND_6), U$8.7 (GND_7), U$19.P$3 (VIN-), U$19.P$4 (GND1), U$25.P$4 (VO-)
unnamed: ..P$21 (OSC1), R32.1
unnamed: ..P$1 (AVDD), C19.2, R19.1
unnamed: Q1.1 (B), R42.2, R44.1
unnamed: ..P$14 (REFIN/OUT), C22.1
unnamed: ..P$28 (DVDD), C21.1, R20.1
unnamed: ..P$27 (/RESET), R21.1
unnamed: ..P$26 (SDI), R22.1
unnamed: ..P$25 (SDO), R23.1
unnamed: ..P$24 (SCK), R24.1
unnamed: ..P$23 (/CS), R25.1
unnamed: ..P$18 (/DRA), R26.1
unnamed: Q1.2 (E), R40.2
unnamed: C14.1, L3.1, U$20.P$2 (VIN+)
unnamed: D1.A, R46.2
unnamed: R45.1, U$19.P$7 (VOUT+)
unnamed: R43.1, U$18.P$7 (VOUT+)
unnamed: R41.1, U$16.P$7 (VOUT+)
unnamed: R39.1, U$12.P$7 (VOUT+)
unnamed: C34.1, L1.1, R19.2
unnamed: R1.1, R3.2, U$2.P$2 (VIN+)
unnamed: R4.1, R5.1, U$9.P$2 (VIN+)
unnamed: R7.1, R9.1, U$12.P$2 (VIN+)
unnamed: R10.1, R11.1, U$16.P$2 (VIN+)
unnamed: R37.1, U$9.P$7 (VOUT+)
unnamed: R35.1, U$2.P$7 (VOUT+)
unnamed: Q3.1 (B), R48.2, R49.1
unnamed: Q3.2 (E), R47.2
unnamed: D3.A, R51.2
unnamed: R12.1, R27.1, U$18.P$2 (VIN+)
unnamed: R36.1, R38.1, U$19.P$2 (VIN+)
unnamed: Q4.1 (B), R53.2, R54.1
unnamed: Q4.2 (E), R52.2
unnamed: D4.A, R55.2
unnamed: D2.A, JP1.1
unnamed: Q5.1 (B), R57.2, R58.1
unnamed: Q5.2 (E), R56.2
unnamed: D5.A, R59.2
unnamed: JP7.1, R18.1, R34.1, R36.2, U$8.1 (LIN1), U$8.8 (LOUT8)
unnamed: JP6.2, R12.2, R17.1, R33.1, U$7.1 (LIN1), U$7.8 (LOUT8)
unnamed: JP4.1, R10.2, R16.1, R31.1, U$6.1 (LIN1), U$6.8 (LOUT8)
unnamed: Q6.1 (B), R61.2, R62.1
unnamed: Q6.2 (E), R60.2
unnamed: JP3.2, R7.2, R15.1, R30.1, U$5.1 (LIN1), U$5.8 (LOUT8)
unnamed: JP8.1, R4.2, R14.1, R29.1, U$4.1 (LIN1), U$4.8 (LOUT8)
unnamed: D6.A, R63.2
unnamed: JP11.2, R1.2, R13.1, R28.1, U$3.1 (LIN1), U$3.8 (LOUT8)
unnamed: Q7.1 (B), R65.2, R66.1
unnamed: Q7.2 (E), R64.2
unnamed: D7.A, R67.2
unnamed: C27.1, L7.1, U$25.P$2 (VIN+)
unnamed: C24.1, L6.1, U$24.P$2 (VIN+)
unnamed: C18.1, L5.1, U$23.P$2 (VIN+)
unnamed: C10.1, L2.1, U$17.P$2 (VIN+)
unnamed: C16.1, L4.1, U$22.P$2 (VIN+)
NRST: JP9.3, R21.2
PA3: JP10.2, R26.2
PA4: JP10.4, R25.2
PA5: JP10.5, R24.2
PA6: JP9.1, R23.2
PA7: JP9.2, R22.2
PB0: JP10.3, R32.2
VCCA: C2.1, C29.2, R40.1, R42.1, R46.1, U$2.P$1 (VDD1), U$17.P$5 (VO+)
VCCB: C7.1, C30.2, R47.1, R48.1, R51.1, U$9.P$1 (VDD1), U$20.P$5 (VO+)
VCCC: C9.1, C31.2, R52.1, R53.1, R55.1, U$12.P$1 (VDD1), U$22.P$5 (VO+)
VCCD: C11.1, C32.2, R56.1, R57.1, R59.1, U$16.P$1 (VDD1), U$23.P$5 (VO+)
VCCE: C12.1, C33.2, R60.1, R61.1, R63.1, U$18.P$1 (VDD1), U$24.P$5 (VO+)
VCCF: C13.1, C36.2, R64.1, R65.1, R67.1, U$19.P$1 (VDD1), U$25.P$5 (VO+)

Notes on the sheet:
(TIM3_CH3)
trebuie sa vad cum era inainte la gnd sau nu
If the output voltage is >5.25
the shunt regulator works and drain current
until the regulation works and
voltage goes down to about <5.25V again.
REF
TS431ACX-RFG
La TS431ACX-RFG nu am avut footprint-ul
si am folosit un tranzistor oarecare
12V input
aici trebuie dioda anti-dl.Victor
pe care l-am conectat ca sa coincida cu footprint-ul din datasheet

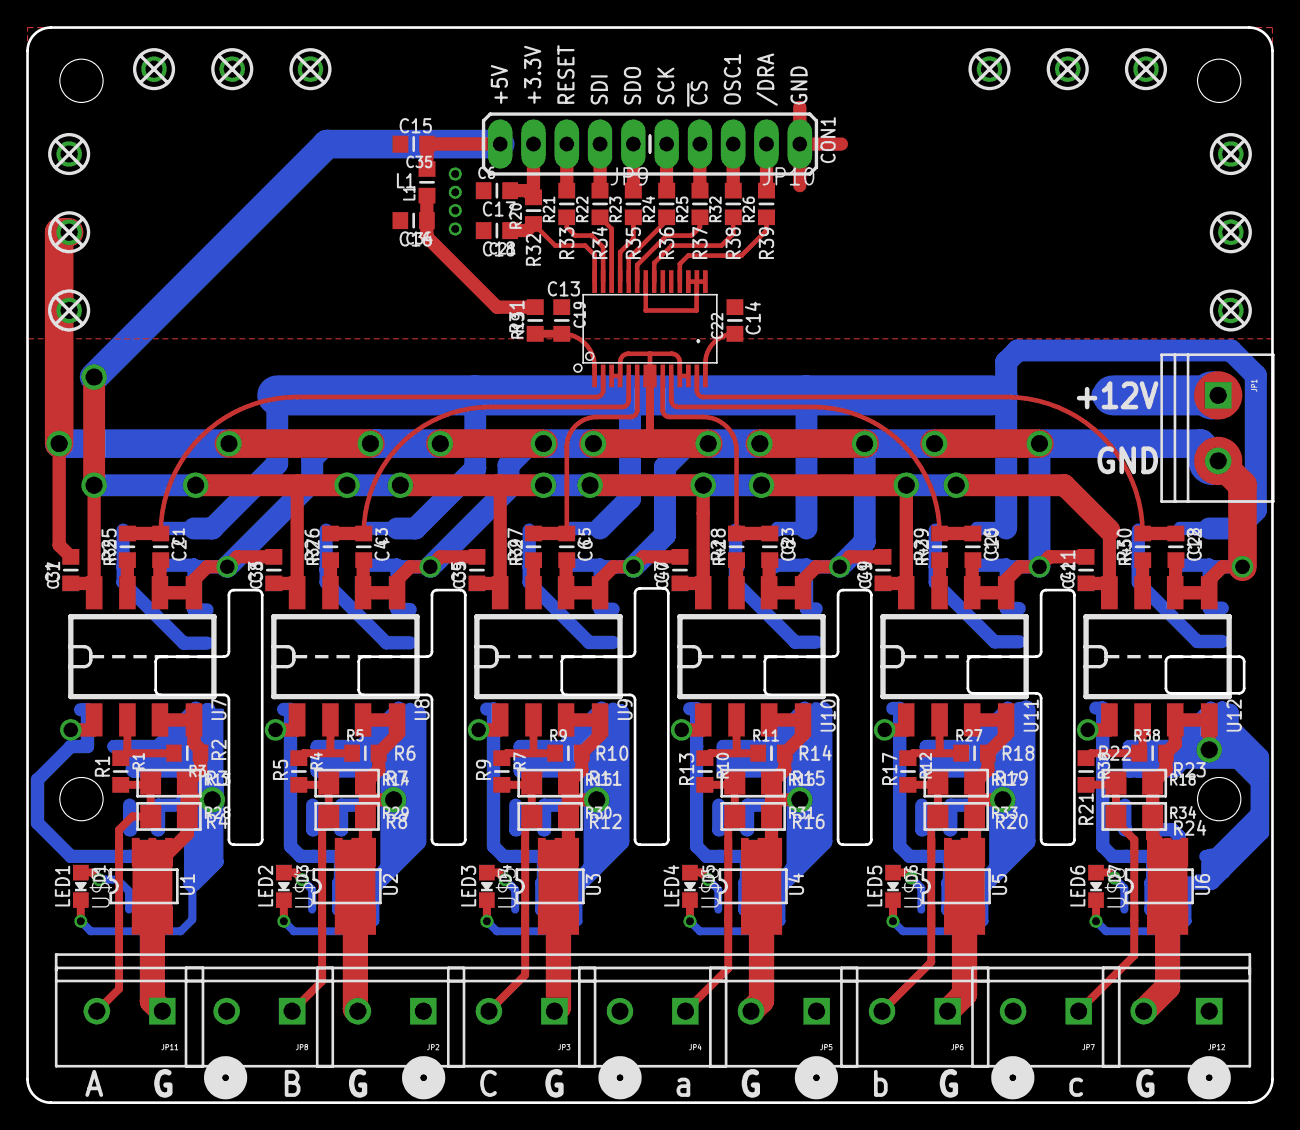
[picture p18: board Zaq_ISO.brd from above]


Board: 2 copper layers, 95.0 x 82.0 mm, 160 parts (67 on the bottom side), 83 nets.

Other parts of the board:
STANDOFF1, STANDOFF6, STANDOFF10, STANDOFF12: STAND-OFF

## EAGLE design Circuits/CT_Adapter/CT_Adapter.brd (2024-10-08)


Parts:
JP7: M025MM; SCREWTERMINAL-5MM-2
JP17, JP18, JP19: M01PTH_LONGPAD; 1X01_LONGPAD
R42: 50ohm; 1206

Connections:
AGND: JP7.1, JP19.1, R42.2
unnamed: JP7.2, JP18.1, R42.1


Board: 2 copper layers, 33.9 x 11.2 mm, 5 parts (1 on the bottom side), 2 nets.

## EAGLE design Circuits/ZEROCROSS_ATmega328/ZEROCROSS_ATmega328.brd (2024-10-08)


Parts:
C1, C6, C10, C11: 100n; _0805MP
C3, C4: 22p; _0805MP
C12: 10uF; _0805MP
IC1: MEGA48/88/168-PU; DIL28-3
JP1: HEADER-1X6; 1X06_OVAL
JP2, JP3, JP4, JP5, JP6, JP11: M01SMD; LUXEON-PAD
JP7, JP8, JP9, JP10, JP12, JP13, JP14, JP15, JP16, JP17, JP50, JP51: M01SNAP-FEMALE; SNAP-FEMALE
JP26, JP27, JP28, JP29, JP30, JP31, JP32, JP33, JP34, JP35, JP36, JP37, JP38, JP39, JP40, JP41, JP42, JP43, JP44, JP45, JP46, JP47, JP48, JP49: M01PTH; 1X01
L1: 10uH; _0805MP
LED1, LED5: LED-3MM-NO_SILK; LED3MM-NS
Q1: CRYSTALHC49U-V; HC49U-V
R4, R5, R10, R11, R12, R13, R14, R15, R16, R17, R18, R19, R20, R21, R22, R23, R24, R25, R26, R27, R28, R29, R30, R31, R32, R33, R34, R35, R36, R37: RESISTOR1206; 1206
R38: 1M; 1206
R39: 10K; _0805MP
R40, R52: 1K; _0805MP

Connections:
IMPULSE: IC1.28 (PC5(ADC5/SCLPCINT13)), JP2.P$1, JP3.P$1
L1: IC1.14 (PB0(ICP1/CLKO/PCINT0)), R17.1
L2: IC1.15 (PB1(OC1A/PCINT1)), R27.1
L3: IC1.16 (PB2(SS/OC1B/PCINT2)), R37.1
MISO: IC1.18 (PB4(MISO/PCINT4)), JP1.5
MOSI: IC1.17 (PB3(MOSI/OC2A/PCINT3)), JP1.6
unnamed: C1.2, IC1.20 (AVCC), L1.2
unnamed: C11.2, C12.2, IC1.7 (VCC), JP1.2, JP47.1, JP48.1, L1.1, R39.1, R52.2
unnamed: R4.1, R5.2
unnamed: R5.1, R10.2
unnamed: R10.1, R11.2
unnamed: R11.1, R12.2
unnamed: R12.1, R13.2
unnamed: R13.1, R14.2
unnamed: R14.1, R15.2
unnamed: R15.1, R16.2
unnamed: R16.1, R17.2
unnamed: R18.1, R19.2
unnamed: R19.1, R20.2
unnamed: R20.1, R21.2
unnamed: R21.1, R22.2
unnamed: R22.1, R23.2
unnamed: R23.1, R24.2
unnamed: R24.1, R25.2
unnamed: R25.1, R26.2
unnamed: R26.1, R27.2
unnamed: R28.1, R29.2
unnamed: R29.1, R30.2
unnamed: R30.1, R31.2
unnamed: R31.1, R32.2
unnamed: R32.1, R33.2
unnamed: R33.1, R34.2
unnamed: R34.1, R35.2
unnamed: R35.1, R36.2
unnamed: R36.1, R37.2
unnamed: C3.2, IC1.9 (PB6(XTAL1/TOSC1/PCINT6)), Q1.2
unnamed: C4.1, IC1.10 (PB7(XTAL2/TOSC2/PCINT7)), Q1.1
unnamed: C10.1, IC1.21 (AREF)
unnamed: C1.1, C3.1, C4.2, C6.1, C10.2, C11.1, C12.1, IC1.8 (GND), IC1.22 (AGND), JP1.1, JP30.1, JP43.1, JP44.1, JP49.1, LED1.K (C), LED5.K (C), R38.1
unnamed: JP7.1, JP12.1, R4.2
unnamed: JP8.1, JP13.1, R18.2
unnamed: JP9.1, JP14.1, R28.2
unnamed: JP10.1, JP15.1, R38.2
unnamed: LED1.A, R40.2
unnamed: JP17.1, JP26.1, JP35.1, JP51.1
unnamed: JP27.1, JP32.1
unnamed: JP33.1, JP34.1, JP36.1
unnamed: JP37.1, JP38.1
unnamed: JP16.1, JP39.1, JP50.1
unnamed: JP28.1, JP40.1
unnamed: JP29.1, JP41.1, JP42.1
unnamed: JP31.1, JP45.1, JP46.1
unnamed: LED5.A, R52.1
RST: C6.2, IC1.1 (PC6(/RESET/PCINT14)), JP1.4, R39.2
RX: IC1.2 (PD0(RXD/PCINT16)), JP4.P$1, JP6.P$1
SCK: IC1.19 (PB5(SCK/PCINT5)), JP1.3, R40.1
TX: IC1.3 (PD1(TXD/PCINT17)), JP5.P$1, JP11.P$1

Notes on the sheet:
N L
AC SUPPLY



Board: 2 copper layers, 86.6 x 77.2 mm, 93 parts (51 on the bottom side), 57 nets.

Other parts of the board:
STANDOFF1, STANDOFF2, STANDOFF3, STANDOFF4: STAND-OFF

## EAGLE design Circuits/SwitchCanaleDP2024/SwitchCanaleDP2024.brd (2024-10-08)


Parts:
C1, C2: CAP_CERAMIC1206; 1206
D1, D2, D3, D4, D5, D6: 1N4148; MINIMELF
JP1, JP9, JP10, JP11, JP12, JP13, JP14, JP15: M025MM; SCREWTERMINAL-5MM-2
JP36, JP41, JP44: M01SNAP-MALE; SNAP-MALE
K1, K2, K9: TX2SA-4.5V; TX2SA
LED2, LED3, LED4, LED5, LED6, LED7: LEDCHIP-LED0805; CHIP-LED0805
Q1, Q2, Q3, Q4, Q5, Q6: TRANSISTOR_NPNWAVE; SOT23-W
R1, R2, R41: 50ohm; 1206
R4, R5, R6: 1K; _0805MP
R28, R31, R34, R36, R38, R40: 1k; _0805MP
R29, R30, R33, R35, R37, R39: 100; _0805MP
U$1: L4941BDT-TR; DPAK

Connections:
2.8V: C2.1, D1.C, D2.C, D3.C, D4.C, D5.C, D6.C, R4.1, R5.1, R6.1, R29.2, R30.1, R33.2, R35.2, R37.2, R39.2, U$1.2 (OUT)
5V: C1.1, JP1.1, U$1.1 (IN)
AGND: C1.2, C2.2, JP1.2, LED2.C, LED3.C, LED4.C, LED5.C, LED6.C, LED7.C, Q1.2 (E), Q2.2 (E), Q3.2 (E), Q4.2 (E), Q5.2 (E), Q6.2 (E), U$1.3 (GND)
GND: JP9.1, JP10.1, JP11.1, JP12.1, JP13.1, JP14.1, R1.1, R2.1, R41.1
unnamed: JP15.2, R31.1, R34.1, R40.1
unnamed: D4.A, K9.1 (+), Q1.3 (C), R29.1
unnamed: K9.8 (S), LED3.A
unnamed: K9.10 (O), LED4.A
unnamed: K9.9, R4.2
unnamed: JP14.2, K9.3 (O)
unnamed: JP9.2, K9.5 (S)
unnamed: JP15.1, R28.2, R36.2, R38.1
unnamed: JP12.2, K2.3 (O)
unnamed: K1.8 (S), LED2.A
unnamed: K1.10 (O), LED5.A
unnamed: K2.8 (S), LED6.A
unnamed: K2.10 (O), LED7.A
unnamed: K2.9, R6.2
unnamed: JP36.2, K9.4, R2.2
unnamed: K1.9, R5.2
unnamed: D1.A, K1.1 (+), Q4.3 (C), R35.1
unnamed: D2.A, K1.12 (-), Q3.3 (C), R33.1
unnamed: JP10.2, K1.3 (O)
unnamed: JP11.2, K1.5 (S)
unnamed: JP41.2, K1.4, R1.2
unnamed: D6.A, K2.1 (+), Q5.3 (C), R37.1
unnamed: JP13.2, K2.5 (S)
unnamed: JP44.2, K2.4, R41.2
unnamed: Q5.1 (B), R38.2
unnamed: Q6.1 (B), R40.2
unnamed: D5.A, K2.12 (-), Q6.3 (C), R39.1
unnamed: D3.A, K9.12 (-), Q2.3 (C), R30.2
unnamed: Q2.1 (B), R31.2
unnamed: Q1.1 (B), R28.1
unnamed: Q3.1 (B), R34.2
unnamed: Q4.1 (B), R36.1

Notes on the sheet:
EE2-3SNUH
RELEELE SUNT
ATENTIE LA PLANURILE DE MASA
PARTEA DE ALIMENTARE NU ESTE ACEEASI CU
SEMNALELE SI OSCILOSCOPUL



Board: 2 copper layers, 99.8 x 67.6 mm, 57 parts (4 on the bottom side), 36 nets.

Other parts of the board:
STANDOFF2, STANDOFF3, STANDOFF4, STANDOFF5: STAND-OFF

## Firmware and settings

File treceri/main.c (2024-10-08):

/*************************************************************************************
    Copyright (C) 2024 Nedelcu Bogdan Sebastian
    This code is free software: you can redistribute it and/or modify it 
    under the following conditions:
    1. The use, distribution, and modification of this file are permitted for any 
       purpose, provided that the following conditions are met:
    2. Any redistribution or modification of this file must retain the original 
       copyright notice, this list of conditions, and the following attribution:
       "Original work by Nedelcu Bogdan Sebastian."
    3. The original author provides no warranty regarding the functionality or fitness 
       of this software for any particular purpose. Use it at your own risk.
    By using this software, you agree to retain the name of the original author in any 
    derivative works or distributions.
    ------------------------------------------------------------------------
    This code is provided as-is, without any express or implied warranties.
**************************************************************************************/

/*******************************************************************
 *
 * Compute RMS voltage and phases of the signals.
 * Recompute after each Modbus interrogation.
 *
 * The MCP3903 ADC registers configuration is explained in the last function.
 *
 * The ADC sampling clock is derived from the TIM2_CH2 clock of 3 MHz:
 *
 *                        MCLK                    AMCLK                      DMCLK
 *     TIM2_CH2 ( 3 MHz ) ----> Prescaller ( /1 ) ----> Clock Divider ( /4 ) ---->
 *
 *     DMCLK                           DRCLK
 *     ----> OSR Clock Divider ( /64 ) ----> ADC sample frquency ( 11718.75 Hz )
 *
 *
 * Used pins:
 *
 *    PB11 ZERO-CROSS INPUT
 *
 *    PA1 - OSC1 3MHz (TIM2_CH2) ADC
 *    PA2 - USED TO CAPTURE /DRA FROM ADC
 *
 *    PA3 - CS SRAM
 *    PA4 - SS ADC
 *    PA5 - SCK ADC/SRAM
 *    PA6 - MISO ADC/SRAM
 *    PA7 - MOSI ADC/SRAM
 *
 *    RELAYS
 *    ------
 *    B12  -  K1
 *    B9   -  K2
 *    B13  -  K3
 *    B8   -  K4
 *    B14  -  K5
 *    B7   -  K6
 *    B15  -  K7
 *    B6   -  K8
 *
 *    B0   - SWITCH TO HIGH SIDE DP CHANELS (A,B,C)
 *    B1   - SWITCH TO LOW SIDE DP CHANELS (a,b,c)
 *
 *    If we need to store signed values we use 2's complement
 *    int16_t val = -100;
 *    uint16_t number = (uint16_t) val
 *
 *    The sampling frequency is:
 *        Fs = 11718.75  => we have data ready each 85.33uS
 *
 *    Number of samples is:
 *        num_points = 2048
 *
 *    How many samples we have in one period of 20 ms
 *        Fs / 50 Hz fundamental = 234.375 samples / period of 20 ms
 *
 *    How many periods we have in 2048 samples:
 *        num_points / 234.375 samples per period = 8.7381333 periods
 *
 *    FFT bin frequency:
 *        bin_freq = Fs / nsamples = 5.7220458984375 Hz/bin
 *
 *    Frequency bin near 50 Hz is at index 9 in FFT
 *        of frequency = bin_freq * 9 FFT bin = 51.4984130859375 Hz
 *
 *    The phase difference between the signal's true frequency (50 Hz) and the FFT bin 9
 *    frequency (51.4984 Hz) it will be calculated and substracted from the phase.
 *
 *    The difference in angular frequency is:
 *        delta_phase = 2PI × (fbin - fsignal) = 2PI × (51.4984130859375 - 50) = 2PI × 1.4984130859375 = 9.4148 rad/s
 *
 *    The FFT gives us the phase at bin 9 for the frequency 51.4984 Hz, the signal at 50 Hz will
 *    have advanced by a phase difference during the length of the signal.
 *
 *    Let T be the total duration of the signal:
 *        T = num_points / sample_rate = 2048 / 11718.75 = 0.174762666 seconds
 *
 *    The total phase shift over this time T is:
 *        phase_difference = delta_phase × T = 9.4148 × 0.174762666 = 1.646 rad = 94.272°
 *
 *    So, the phase at bin 9 is approximately 94.272° ahead of the true phase at 50 Hz.
 *
 ********************************************************************/

#include "stm32f10x.h"
#include "math.h"
#include "main.h"
#include "mbutils.h"
#include "mb.h"

// Flattop Window: If the purpose of the test focus more on the energy value of a
// certain periodic signal frequency point. For example for Upeak, Upeak-peak, Urms,
// then the accuracy of its amplitude is more important, and a window with slighty
// wider lobes is better.
// The Flat Top window has a flatter passband, which helps retain accurate amplitude
// and phase information, particularly when analyzing signals where frequency peaks
// must be well-isolated. Since the window decreases the leakage, the phase extraction
// becomes more accurate. However, keep in mind that this window broadens the peaks,
// so you might sacrifice some resolution in the frequency domain.
/*void generate_flat_top_window(float *window, size_t num_points) {
    // Flat Top window coefficients
    const float a0 = 1.0;
    const float a1 = 1.93;
    const float a2 = 1.29;
    const float a3 = 0.388;
    const float a4 = 0.028;

    for (size_t n = 0; n < num_points; n++) {
        // Compute the normalized index value
        float factor = (2 * PI * n) / (num_points - 1);

        // Apply the Flat Top window function
        window[n] = a0
                  - a1 * cos(factor)
                  + a2 * cos(2 * factor)
                  - a3 * cos(3 * factor)
                  + a4 * cos(4 * factor);
    }
}
*/
const float flattop_window[] = {
0.000000, -0.000001, -0.000004, -0.000008, -0.000014, -0.000022, -0.000032, -0.000043,
-0.000056, -0.000071, -0.000088, -0.000106, -0.000127, -0.000149, -0.000173, -0.000198,
-0.000226, -0.000255, -0.000286, -0.000319, -0.000354, -0.000390, -0.000429, -0.000469,
-0.000511, -0.000556, -0.000602, -0.000650, -0.000700, -0.000751, -0.000805, -0.000861,
-0.000919, -0.000978, -0.001040, -0.001104, -0.001170, -0.001238, -0.001308, -0.001380,
-0.001454, -0.001530, -0.001609, -0.001690, -0.001773, -0.001858, -0.001945, -0.002035,
-0.002127, -0.002221, -0.002317, -0.002416, -0.002517, -0.002621, -0.002727, -0.002836,
-0.002947, -0.003060, -0.003176, -0.003295, -0.003416, -0.003539, -0.003666, -0.003795,
-0.003926, -0.004061, -0.004198, -0.004338, -0.004480, -0.004626, -0.004774, -0.004926,
-0.005080, -0.005237, -0.005397, -0.005560, -0.005726, -0.005896, -0.006068, -0.006243,
-0.006422, -0.006604, -0.006789, -0.006977, -0.007169, -0.007364, -0.007562, -0.007764,
-0.007969, -0.008178, -0.008390, -0.008606, -0.008826, -0.009048, -0.009275, -0.009505,
-0.009740, -0.009977, -0.010219, -0.010465, -0.010714, -0.010967, -0.011224, -0.011486,
-0.011751, -0.012020, -0.012294, -0.012571, -0.012853, -0.013139, -0.013429, -0.013724,
-0.014022, -0.014326, -0.014633, -0.014945, -0.015262, -0.015583, -0.015908, -0.016239,
-0.016574, -0.016913, -0.017257, -0.017606, -0.017960, -0.018319, -0.018683, -0.019051,
-0.019424, -0.019803, -0.020186, -0.020575, -0.020968, -0.021367, -0.021771, -0.022180,
-0.022594, -0.023014, -0.023439, -0.023869, -0.024305, -0.024746, -0.025193, -0.025645,
-0.026103, -0.026567, -0.027036, -0.027510, -0.027991, -0.028477, -0.028968, -0.029466,
-0.029970, -0.030479, -0.030994, -0.031515, -0.032042, -0.032576, -0.033115, -0.033660,
-0.034212, -0.034769, -0.035333, -0.035903, -0.036479, -0.037061, -0.037650, -0.038245,
-0.038846, -0.039454, -0.040068, -0.040688, -0.041315, -0.041949, -0.042589, -0.043235,
-0.043888, -0.044548, -0.045215, -0.045887, -0.046567, -0.047253, -0.047946, -0.048646,
-0.049353, -0.050066, -0.050786, -0.051513, -0.052247, -0.052987, -0.053735, -0.054489,
-0.055250, -0.056018, -0.056794, -0.057576, -0.058365, -0.059161, -0.059964, -0.060774,
-0.061591, -0.062415, -0.063246, -0.064084, -0.064929, -0.065781, -0.066640, -0.067507,
-0.068380, -0.069261, -0.070148, -0.071043, -0.071945, -0.072854, -0.073770, -0.074693,
-0.075623, -0.076560, -0.077504, -0.078456, -0.079414, -0.080380, -0.081352, -0.082332,
-0.083319, -0.084312, -0.085313, -0.086321, -0.087336, -0.088357, -0.089386, -0.090422,
-0.091464, -0.092514, -0.093570, -0.094634, -0.095704, -0.096781, -0.097865, -0.098956,
-0.100053, -0.101157, -0.102268, -0.103386, -0.104510, -0.105641, -0.106779, -0.107923,
-0.109073, -0.110230, -0.111394, -0.112564, -0.113740, -0.114923, -0.116112, -0.117308,
-0.118509, -0.119717, -0.120931, -0.122151, -0.123377, -0.124609, -0.125847, -0.127090,
-0.128340, -0.129595, -0.130857, -0.132123, -0.133396, -0.134674, -0.135957, -0.137246,
-0.138541, -0.139840, -0.141145, -0.142455, -0.143770, -0.145090, -0.146415, -0.147745,
-0.149080, -0.150419, -0.151763, -0.153112, -0.154465, -0.155823, -0.157185, -0.158551,
-0.159922, -0.161296, -0.162675, -0.164057, -0.165443, -0.166833, -0.168227, -0.169624,
-0.171024, -0.172428, -0.173835, -0.175246, -0.176659, -0.178075, -0.179494, -0.180916,
-0.182341, -0.183767, -0.185197, -0.186628, -0.188062, -0.189498, -0.190936, -0.192375,
-0.193817, -0.195259, -0.196704, -0.198149, -0.199596, -0.201044, -0.202493, -0.203943,
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
};

// FFT buffer
float xyData[4096];

// Min and max of the leakage current signals
float minCH0 = 1000.0;
float minCH1 = 1000.0;
float minCH2 = 1000.0;
float minCH3 = 1000.0;
float minCH4 = 1000.0;
float minCH5 = 1000.0;

float maxCH0 = -1000.0;
float maxCH1 = -1000.0;
float maxCH2 = -1000.0;
float maxCH3 = -1000.0;
float maxCH4 = -1000.0;
float maxCH5 = -1000.0;

// RMS of the signals
float RMSVoltageCH0 = 0;
float RMSVoltageCH1 = 0;
float RMSVoltageCH2 = 0;
float RMSVoltageCH3 = 0;
float RMSVoltageCH4 = 0;
float RMSVoltageCH5 = 0;

// Phases of the signals
float phaseCH0 = 0;
float phaseCH1 = 0;
float phaseCH2 = 0;
float phaseCH3 = 0;
float phaseCH4 = 0;
float phaseCH5 = 0;

// SPI1 on PORTA
#define SS     GPIO_Pin_4  // Chip select of the MCP3903 ADC
#define SCK    GPIO_Pin_5  // Clock
#define MISO   GPIO_Pin_6  // Data out
#define MOSI   GPIO_Pin_7  // Data in

// ADC chipselect pin
#define MCP3903_CS_low    GPIO_ResetBits(GPIOA, SS)
#define MCP3903_CS_high   GPIO_SetBits(GPIOA, SS)

// Zero cross signal input pin
#define WaitHiSIG   while ((GPIOB->IDR & GPIO_Pin_11) == 0)
#define WaitLoSIG   while ((GPIOB->IDR & GPIO_Pin_11) != 0)

// ADC dataready pin
#define WaitHiDRA   while ((GPIOA->IDR & GPIO_Pin_2) == 0)
#define WaitLoDRA   while ((GPIOA->IDR & GPIO_Pin_2) != 0)

// Bytes for ADC values (2 bytes each 16 bit value)
uint8_t MSB0, LSB0;
uint8_t MSB1, LSB1;
uint8_t MSB2, LSB2;
uint8_t MSB3, LSB3;
uint8_t MSB4, LSB4;
uint8_t MSB5, LSB5;

// Counter for the 4096 samples of the signal
uint16_t sample_counter;

// Phase shift counter in nanoseconds between zerocross and the actual
// ADC start to acquire data, based on /DRA pin of the ADC
volatile uint32_t CPUTicks;

uint8_t flag = 0;

// Functions definition for the SPI pheripheral and the ADC
void SPI_init(void);
uint8_t SPISend(uint8_t data);
void MCP3903_init(void);

// SRAM Hold line override
#define HOLD 1

// SRAM opcodes
#define RDSR  5
#define WRSR  1
#define READ  3
#define WRITE 2

#define RAMCLK1M   1

// SRAM modes
#define BYTE_MODE   (0x00 | HOLD)
#define PAGE_MODE   (0x80 | HOLD)
#define STREAM_MODE (0x40 | HOLD)

// SRAM chipselect pin
#define CS     GPIO_Pin_3

// SRAM chipselect pin
#define ENABLE_RAM    GPIO_ResetBits(GPIOA, CS)
#define DISABLE_RAM   GPIO_SetBits(GPIOA, CS)

// Always do a &0xFF mask to assure we don't have sign problems
#define MSB(x)       ( x >> 8 ) & 0xFF
#define LSB(x)       (x & 0xFF)
#define COMB2WORD(_MSB,_LSB)   ( ( _MSB & 0xFF ) << 8 ) | ( _LSB & 0xFF );  // Bytes to word

#define TO_HEX(i) (i <= 9 ? '0' + i : 'A' - 10 + i) // DEC -> HEX
#define TO_DEC(i) (i <= '9'? i - '0': i - 'A' + 10) // HEX -> DEC
#define CHECK_BIT(var,pos) ((var) & (1<<(pos)))  // Check if bit is set

// Volatile counter updated in Systick interrupt
volatile uint32_t TimingDelay;

void Delay(volatile uint32_t nTime)
{
    TimingDelay = nTime;

    while(TimingDelay != 0);
}

// Flag to to know when the Modbus data sending has complete
volatile uint8_t Modbus_End_Transmission_Flag;

// Modbus dataspace
u16 usRegHoldingBuf[40+1];  // 0..40 Holding registers
u8  usRegCoilBuf[64/8+1];  // 0..64  Coils

void writeCoil (uint8_t coil_index, uint8_t state) {
    uint8_t coil_offset=coil_index/8;
    if (state == 1)
        usRegCoilBuf[coil_offset] |= (1<<(coil_index%8));
    else usRegCoilBuf[coil_offset] &= ~(1<<(coil_index%8));
}

uint8_t getCoil (uint8_t coil_index) {
    uint8_t coil_byte=usRegCoilBuf[coil_index/8];
    if (coil_byte && (1<<(coil_index%8))) return 1;
    else return 0;
}

void writeHoldingRegister (uint8_t reg_index, uint16_t reg_val) {
    usRegHoldingBuf[reg_index] = reg_val;
}

uint16_t readHoldingRegister (uint8_t reg_index) {
    return usRegHoldingBuf[reg_index];
}

// DWT pheriperal registers
volatile uint32_t *DWT_CONTROL = (volatile uint32_t *)0xE0001000;
volatile uint32_t *DWT_CYCCNT  = (volatile uint32_t *)0xE0001004;
volatile uint32_t *SCB_DEMCR   = (volatile uint32_t *)0xE000EDFC;

void DWT_Enable (void) {
    // Enable the use of DWT
    *SCB_DEMCR = *SCB_DEMCR | 0x01000000;
    // Reset the counter
    *DWT_CYCCNT = 0;
    // Enable cycle counter
    *DWT_CONTROL = *DWT_CONTROL | 1;
}

#define PI        3.1415926535897932384626433832795
#define DEG2RAD   0.01745329251994329576923690768489
#define RAD2DEG   57.295779513082320876798154814105  // 180/PI
#define EPSILON   1e-8 // Small value for zero comparison

// Calculates the FFT phase at a given frequency index.
// Input: data is complex FFT Re[V(0)],Im[V(0)], Re[V(1)],Im[V(1)],...
// Input: nn is the number of points in the data and in the FFT,
//           nn must be a power of 2
// Input: k is frequency index 0 to nn/2-1
//        E.g., if nn = 4096, then k can be 0 to 2047
// Output: Phase at this frequency
// data is an array of 2*nn elements
// returns 0 if k >= nn/2
float myfftPhase (float data[], unsigned long nn, uint16_t k) {
    if (k >= nn / 2) {
        return 0.0; // out of range
    }

    // Extract the real and imaginary parts of the k-th element
    float real_part = data[2 * k];
    float imag_part = data[2 * k + 1];

    // Handle the case when both real and imaginary parts are zero (undefined phase)
    if (fabs(real_part) < EPSILON && fabs(imag_part) < EPSILON) {
        return 0.0; // phase is undefined
    }

    // Calculate the angle in radians using atan2
    float angle_rad = atan2(imag_part, real_part);

    // Convert the angle to degrees
    float angle_deg = angle_rad * RAD2DEG;

    angle_deg += 137.1126;
    
    if (angle_deg < 0.0) {
        angle_deg += 360.0;
    }
    
    return angle_deg;
}

// Apply the Flat Top window to the signal
void apply_flattop_window(float *signal, const float *flattop_window, size_t num_points) {
    for (size_t n = 0; n < num_points; n++) {
        signal[n * 2] = signal[n * 2] * flattop_window[n]; // Apply the window to the real part
    }
}

// Load to xyData buffer the selected signal from the SRAM memory
void load_Channel_To_FFTbuffer (uint8_t channel) {
    uint16_t i;

    // Start reading from adress zero
    ENABLE_RAM;
    SPISend(READ);
    SPISend(0x00);  // MSB
    SPISend(0x00);  // LSB

    i = 0;
    while (i < 4096) {
        // Read all 6 channels at once from SRAM
        MSB0 = SPISend(0xFF); LSB0 = SPISend(0xFF);
        MSB1 = SPISend(0xFF); LSB1 = SPISend(0xFF);
        MSB2 = SPISend(0xFF); LSB2 = SPISend(0xFF);
        MSB3 = SPISend(0xFF); LSB3 = SPISend(0xFF);
        MSB4 = SPISend(0xFF); LSB4 = SPISend(0xFF);
        MSB5 = SPISend(0xFF); LSB5 = SPISend(0xFF);

        // We use MSB0 and LSB0 for every channel to conserve memory
        switch (channel) {
            //case 0:
            //    MSB0 = MSB0;  :)
            //    LSB0 = LSB0;
            //    break;
            case 1:
                MSB0 = MSB1;
                LSB0 = LSB1;
                break;
            case 2:
                MSB0 = MSB2;
                LSB0 = LSB2;
                break;
            case 3:
                MSB0 = MSB3;
                LSB0 = LSB3;
                break;
            case 4:
                MSB0 = MSB4;
                LSB0 = LSB4;
                break;
            case 5:
                MSB0 = MSB5;
                LSB0 = LSB5;
                break;
            default:
                // Optional: Handle invalid channel case if needed
                break;
        }

        // Data is from 2 in 2, Re,Im, Re,Im,...
        // Convert 16 bit ADC values to actual voltage
        xyData[i] = ((float)((int16_t)((MSB0 << 8) | LSB0)) / 32767.0 / 3.0) * 2.39;  // ADC Vref = 2.39V
        // The imaginary side is zero when we load the real signal
        xyData[i + 1] = 0;

        // Each time we load a channel to FFT buffer, we also find the MIN and MAX
        // and update the global variables
        switch (channel) {
            case 0:
                if (xyData[i] > maxCH0) maxCH0 = xyData[i];
                if (xyData[i] < minCH0) minCH0 = xyData[i];
                break;
            case 1:
                if (xyData[i] > maxCH1) maxCH1 = xyData[i];
                if (xyData[i] < minCH1) minCH1 = xyData[i];
                break;
            case 2:
                if (xyData[i] > maxCH2) maxCH2 = xyData[i];
                if (xyData[i] < minCH2) minCH2 = xyData[i];
                break;
            case 3:
                if (xyData[i] > maxCH3) maxCH3 = xyData[i];
                if (xyData[i] < minCH3) minCH3 = xyData[i];
                break;
            case 4:
                if (xyData[i] > maxCH4) maxCH4 = xyData[i];
                if (xyData[i] < minCH4) minCH4 = xyData[i];
                break;
            case 5:
                if (xyData[i] > maxCH5) maxCH5 = xyData[i];
                if (xyData[i] < minCH5) minCH5 = xyData[i];
                break;
            default:
                // Handle unexpected channel values if necessary
                break;
        }

        i += 2;
    }
    DISABLE_RAM;
}

// Helper macro to swap two float values
#define SWAP(a, b) { float temp = (a); (a) = (b); (b) = temp; }
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
int main() {
    unsigned long nn = 4; // Number of data points (must be a power of 2)
    float data[] = {1.0, 0.0,  // First real sample
                    2.0, 0.0,  // Second real sample
                    3.0, 0.0,  // Third real sample
                    4.0, 0.0}; // Fourth real sample

    // Perform the FFT on the input data
    real_fft(data, nn);

    // Output the FFT results
    for (unsigned long i = 0; i < 2 * nn; i += 2) {
        printf("Re[%lu]: %f, Im[%lu]: %f\n", i / 2, data[i], i / 2, data[i + 1]);
    }

    return 0;
}
 */

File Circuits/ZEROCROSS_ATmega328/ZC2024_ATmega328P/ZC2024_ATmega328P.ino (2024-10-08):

/*
 * SOFT ZERO CROSS 
 * 
 * FUSES
 * --------
 * EFUSE = 0xff     // = 0x07
 * HFUSE = 0xde
 * LFUSE = 0xe2
 * 
 */

#define PCINT_PIN 8         // PB0 - PCINT0
#define PCINT_MODE CHANGE
#define PCINT_FUNCTION      getZeroCross

volatile uint8_t oldPort = 0x00;

#define PCMSK *digitalPinToPCMSK(PCINT_PIN)
#define PCINT digitalPinToPCMSKbit(PCINT_PIN)
#define PCIE  digitalPinToPCICRbit(PCINT_PIN)
#define PCPIN *portInputRegister(digitalPinToPort(PCINT_PIN))

#if (PCIE == 0)
#define PCINT_vect PCINT0_vect
#elif (PCIE == 1)
#define PCINT_vect PCINT1_vect
#elif (PCIE == 2)
#define PCINT_vect PCINT2_vect
#else
#error This board doesnt support PCINT ?
#endif

#define INPUT_PIN_LOW       !(PINB & (1<<PB0))
#define INPUT_PIN_HIGH      (PINB & (1<<PB0))

#define SIGHIGH             PORTC |= (1<<PC5)
#define SIGLOW              PORTC &= ~(1<<PC5)

#define LEDON               PORTB |= (1<<PB5)
#define LEDOFF              PORTB &= ~(1<<PB5)
#define LEDTOGGLE           PORTB ^= (1<<PB5)

volatile uint8_t pulse_counter = 0;

void setup() {
  // led pin as output
  DDRB |= (1<<PB5);
  DDRC |= (1<<PC5); // Output pin
     
  // ==== attachPinChangeInterrupt
  // update the old state to the actual state
  oldPort = PCPIN;
  // pin change mask registers decide which pins are enabled as triggers
  PCMSK |= (1 << PCINT);
  // PCICR: Pin Change Interrupt Control Register - enables interrupt vectors
  PCICR |= (1 << PCIE);
}

void loop() {
}

void getZeroCross(void) {
  if (INPUT_PIN_HIGH) {
    SIGHIGH;
    if (pulse_counter++ == 50) {
      pulse_counter = 0;
      LEDTOGGLE; 
    }
  }

  if (INPUT_PIN_LOW) {
    SIGLOW;
  }
}

ISR(PCINT_vect) {  
  PCINT_FUNCTION();
}

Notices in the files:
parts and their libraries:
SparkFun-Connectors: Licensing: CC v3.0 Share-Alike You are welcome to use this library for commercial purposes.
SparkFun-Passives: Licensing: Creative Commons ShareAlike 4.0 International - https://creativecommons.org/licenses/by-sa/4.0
